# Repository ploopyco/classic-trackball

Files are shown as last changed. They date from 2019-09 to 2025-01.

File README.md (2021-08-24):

# The Ploopy Trackball

By some stroke of luck, you've made your way here. The Ploopy Trackball. Your life will never be the same.

This repository contains all of the design and production files necessary to make a Ploopy Trackball. We've also included some kick-ass documentation in the Wiki on how to get it made, assemble it, and program it.

What are you waiting for? Your new life awaits.

## QMK?!

As of November 13th, 2020, kits bought from the [Ploopy store](https://ploopy.co/product-category/trackball/classic/) come with QMK preloaded. Check out the Wiki for instructions on how to load new firmware onto your device. (It's super easy!)

## Under what license is this released?

The firmware is released under GPLv3. The hardware is released under OHL CERN v1.2. Check the respective directories for full license text.

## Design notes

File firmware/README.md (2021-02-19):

# Deprecation Notice

As of November 13th, 2020, this firmware is considered DEPRECATED and should no longer be used.

If you purchased an official Ploopy Kit and received a notice of shipment prior to November 13th, your kit includes this firmware. If your kit shipped after this date, it comes with [QMK](https://github.com/qmk/qmk_firmware).

This firmware will still work with PCBs of version R1.005, and the firmware in [R1.004 branch](https://github.com/ploopyco/trackball/tree/r1.004) will still work with PCBs of version R1.004 and previous. But you really ought to switch to QMK. It's the shit.

Sample builds of QMK are included here, for board versions prior to R1.005 (the `rev1` hex) as well as the R1.005 board and later (the `rev1_005` hex). They were built using QMK version 0.11.1.

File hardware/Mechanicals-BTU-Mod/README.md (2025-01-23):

# Ploopy BTU Mod

The roller bearings used in the Ploopy Trackball are nice, but with the standard ball they might not feel as smooth or as low-friction as you'd like. The prompt for this mod was "what if we replaced them with ball transfer units?"

It turns out - good things happen!

Ball transfer units (or BTUs) are omnidirectional bearings, as opposed to the single-direction roller bearings the Ploopy Trackball uses by default. This means you're never rolling the ball in the "wrong direction" for one of them.

This mod is a new 3D-printable top piece for the Ploopy which contains holes for ball transfer units instead of roller bearings.

Designer: [George Bryant](https://github.com/gbrnt) with help and bearing advice from [/u/d4baller](https://reddit.com/user/d4baller)
## Versions
### REVD-BTU
This version is the version you should use if you have a REV D Ploopy top.
You can check this on the underside of your original top - there should be a large letter D,
and your screws will be self-tapping screws.
It supports both the original ball and the new larger (45mm) ball.

### REVC-BTU
This version is the version you should use if you have a REV C Ploopy top.
You can check this on the underside of your original top - there should be a large letter C,
and your screws will be M3 screws.
It supports both the original ball and the new larger (45mm) ball.

### v3 and v4
These versions are too small to fit the new larger ball.
They've been removed, but you can still find them in the commit history.
v3 is a non-editable version that exposes the edge of one BTU, and v4 is an editable FreeCAD version.
Here's what they look like:

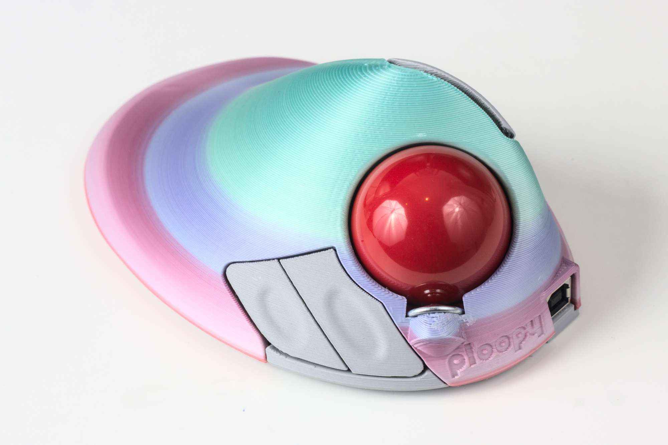
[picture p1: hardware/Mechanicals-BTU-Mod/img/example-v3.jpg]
A trackball with this mod v3 installed


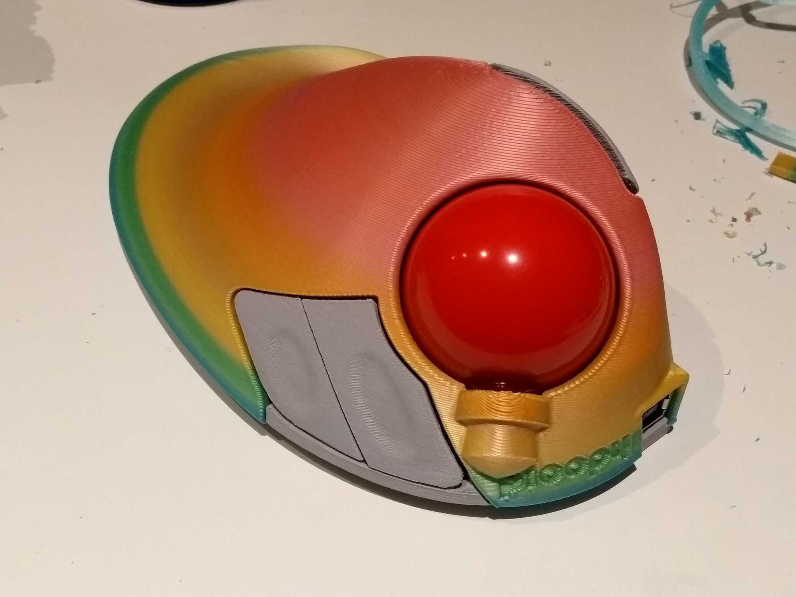
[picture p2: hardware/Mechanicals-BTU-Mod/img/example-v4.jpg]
A trackball with the v4 mod installed


## Buying the BTUs
The particular BTU this mod is designed for is the Bosch-Rexroth R053010810, or KU-B8-OFK. A set of three is about 20-30 USD, depending on where in the world you are and where you buy them from. Here are some sources we've found so far:

* [Bosch-Rexroth](https://www.boschrexroth.com/en/xc/products/product-groups/linear-motion-technology/ball-transfer-units-and-tolerance-rings/ball-transfer-units/r0530-with-sheet-stee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) - UK and worldwide, but requires you to be a company (e.g. have a VAT number)
* [Livhaven](https://store.livhaven.com/r053010810-bosch-rexroth-ball-transfer-unit) - US-based. Doesn't require company information, but overseas shipping is expensive.
* [Uberbearings](https://www.uberbearings.com/R053010810KU-B8-OFK-BOS) - Ships from UK worldwide to private customers. Much cheaper shipping than the other Europe based ones.
* [L-System](https://l-system.nu/webshop/linear-technology/ball-transfer-units-and-tolerance-rings/ball-transfer-units/type-r0530/ball-transfer-unit-ku-b8-ofk/) - Sweden-based. Might allow private customers to buy.
* [Spareparts](https://www.sp-spareparts.com/en/p/r053010810-bosch-rexroth) - Ireland-based. Ships to UK and maybe elsewhere. Does sell to private customers.
* [Rodivago](https://rodavigo.net/es/p/bola-transportadora-con-carter-de-metal-laminado-ref-053010810/557053010810) - Spain-based. May require being a company.
* For other sources, try Bosch-Rexroth's [contact locator tool](https://addresses.boschrexroth.com/) - find a distributor near you, and search for the bearing part number on their website.

(Some people consider buying cheaper nylon BTUs. But they have high internal friction and the ball actually slides on them like on a static bearing, which makes them pointless.)

## Printing
Follow [Ploopyco's recommendations for print settings](https://github.com/ploopyco/trackball/wiki/Appendix-B%3A-3D-printed-parts). It's also highly recommended to enable support interface and splitting the support into chunks, as otherwise it can be very hard to remove.

## Assembly
* Remove all support material from the print.
* Inspect the holes the BTUs will sit in to make sure there are no lumps inside the hole. File/sand/cut them off if needed.
* Install the BTUs by pushing them into the holes.
* Check the BTUs are fully installed by putting the ball on top. It shouldn't scrape on the top surface. If it did one or more of the BTUs might not be fully pushed in.
* Check that the holes for the threaded inserts are clear (You could carefully drill them out with a 4mm drill bit).
* Install 4 M3 threaded inserts into the bottom of the part using a soldering iron (see note below).
* Remove the original top piece from your Ploopy trackball.
* Remove the secondary button piece, grind off the stop (see below) and reinstall.
* Install the new top piece on the trackball.
* Give it a try!

### Threaded inserts (Ignore if using REV D)
You'll need 4 heat-set M3 threaded inserts for the screws which attach the top to the base.
These can be bought from a variety of sources - you should use ones which are made for 4.0 - 4.2mm holes.
Recommendations for installing these are in the [Ploopy trackball assembly guide](https://github.com/ploopyco/trackball/wiki/Ploopy-Trackball-Kit-Assembly).

### Modifying secondary buttons
There is a small tab on the secondary buttons which collides with the closest BTU. It needs to be sanded, filed or cut off. It is indicated in red in the image below:

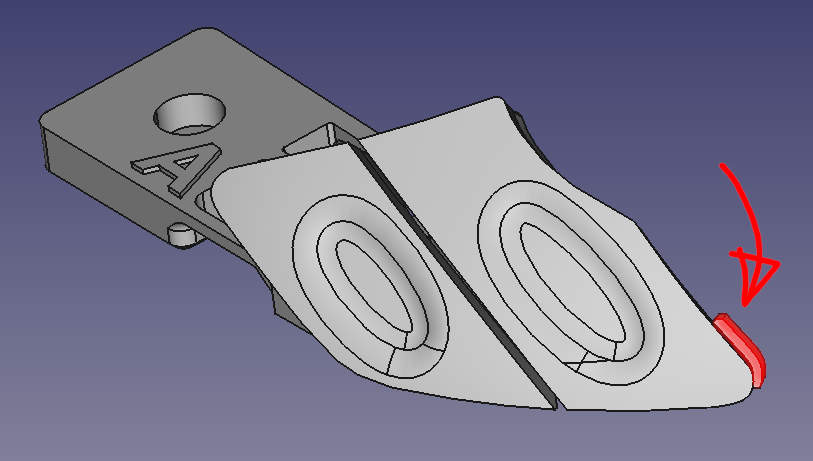
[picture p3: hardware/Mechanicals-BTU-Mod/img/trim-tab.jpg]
Ploopy secondary buttons, with the tab on the end highlighted in red


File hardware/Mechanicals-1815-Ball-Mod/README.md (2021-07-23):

This Top accommodates balls that are 1.815" in diameter, a ball that can be found in such devices as the Microsoft Trackball Explorer.

Credit goes to an anonymous redditor. Thanks for the contribution!

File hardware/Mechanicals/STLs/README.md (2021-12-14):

The files in each "Revision" directory are designed to work with each other. For instance, all of the files in Revision A are designed to work as a unit.

**NOTE** that even though a Revision is marked with a letter, not all of the parts have this letter. For instance, in Revision D, the buttons are actually marked with a C. This is intentional.

Files in this directory are common to all revisions.

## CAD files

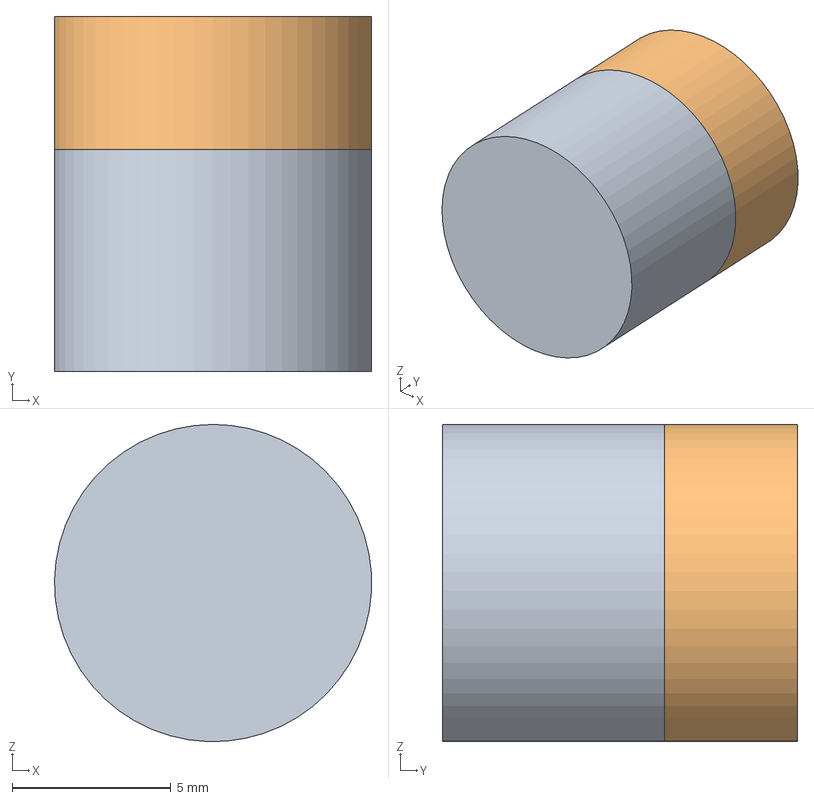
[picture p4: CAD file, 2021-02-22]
hardware/Mechanicals/STEPs/Bit Bearing Press Complete.step
9.99 x 11.2 x 10.00 mm

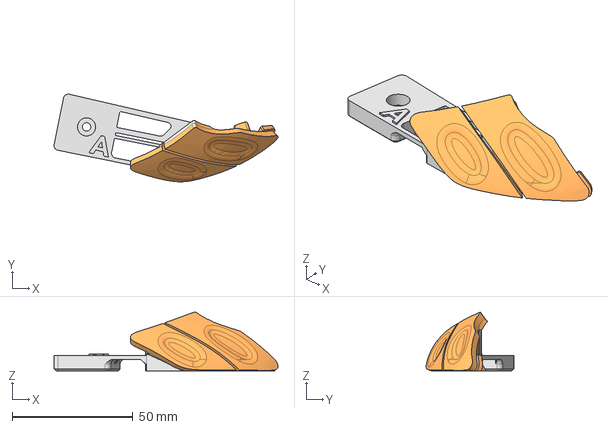
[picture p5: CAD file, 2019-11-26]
hardware/Mechanicals/STEPs/Revision C/Secondary Buttons.stp
92.8 x 36.3 x 24.3 mm

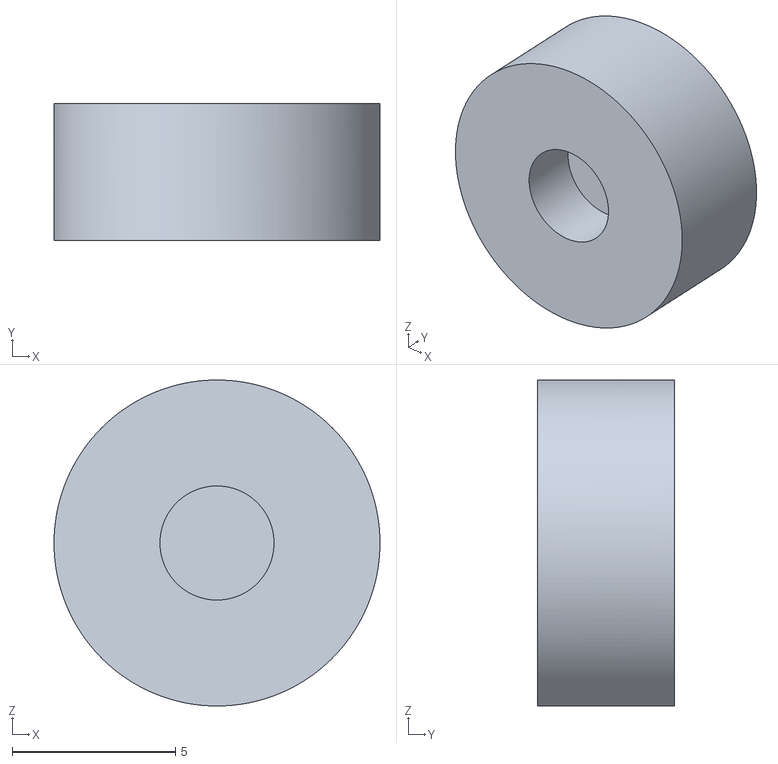
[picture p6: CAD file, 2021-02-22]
hardware/Mechanicals/STLs/Kit Bearing Press Top.stl
10.00 x 4.20 x 10.00

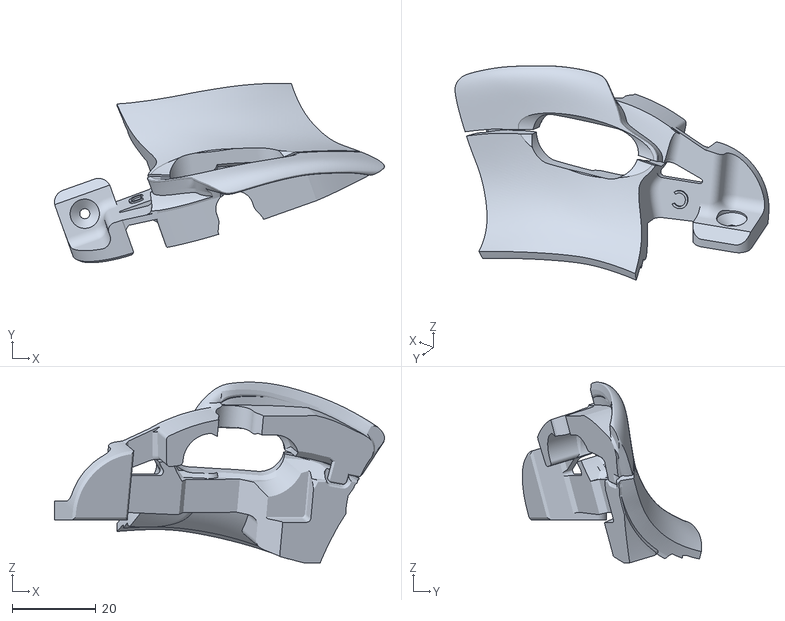
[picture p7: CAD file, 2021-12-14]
hardware/Mechanicals/STLs/Revision D/Primary Buttons.STL
78.9 x 42.9 x 43.2

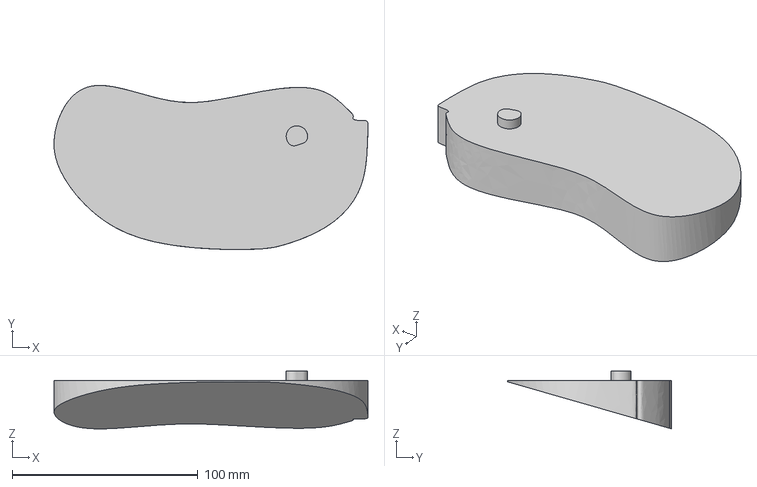
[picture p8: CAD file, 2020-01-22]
hardware/Mechanicals/STEPs/Wedge.stp
169.1 x 88.4 x 31.0 mm

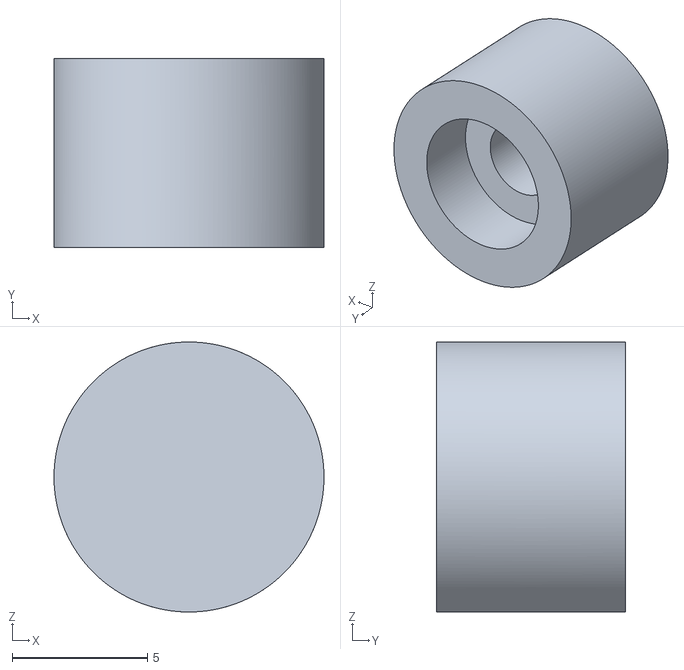
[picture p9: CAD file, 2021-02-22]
hardware/Mechanicals/STLs/Kit Bearing Press Bottom.stl
10.00 x 7.00 x 10.00

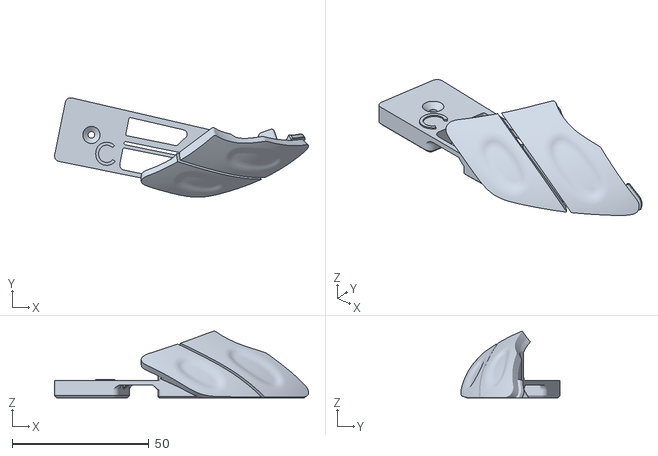
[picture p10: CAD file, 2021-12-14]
hardware/Mechanicals/STLs/Revision D/Secondary Buttons.STL
92.8 x 36.3 x 24.3

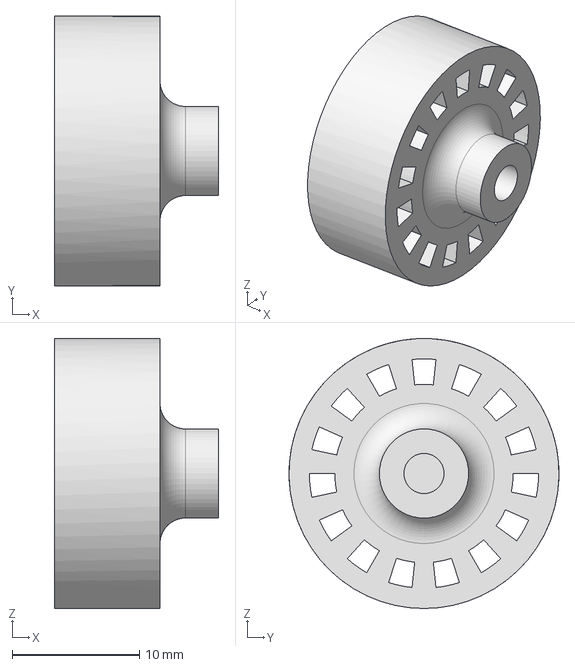
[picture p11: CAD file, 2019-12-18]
hardware/Mechanicals/STEPs/ScrollWheel.stp
12.9 x 21.2 x 21.2 mm

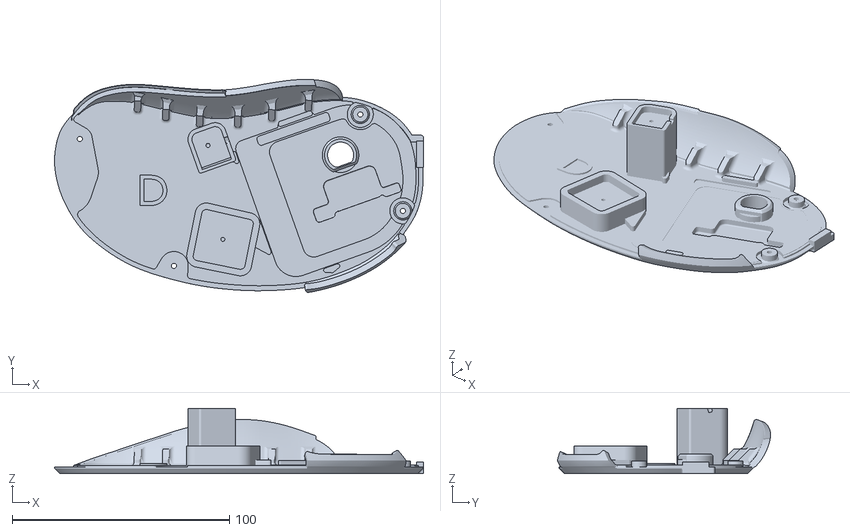
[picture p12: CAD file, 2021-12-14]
hardware/Mechanicals/STLs/Revision D/Bottom.STL
170.0 x 98.3 x 30.0

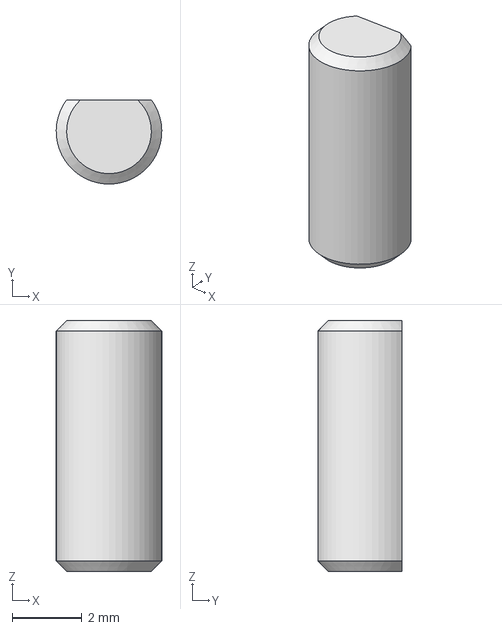
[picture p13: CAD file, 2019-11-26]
hardware/Mechanicals/STEPs/RollerBearingDowel.stp
3.03 x 2.42 x 7.20 mm

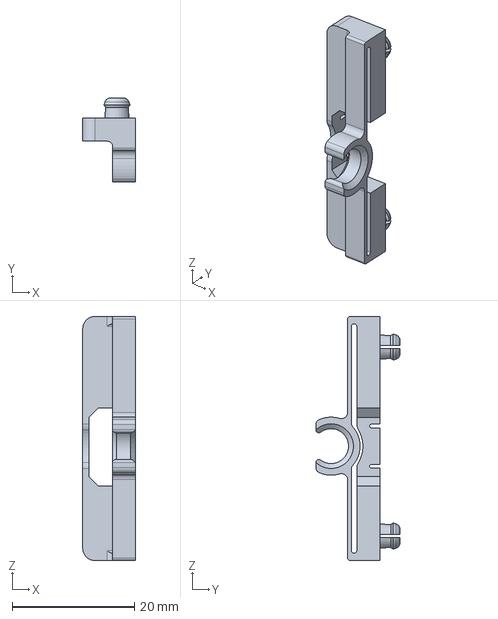
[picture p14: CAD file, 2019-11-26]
hardware/Mechanicals/STEPs/ScrollWheelHolderHolder.stp
8.60 x 13.8 x 39.9 mm

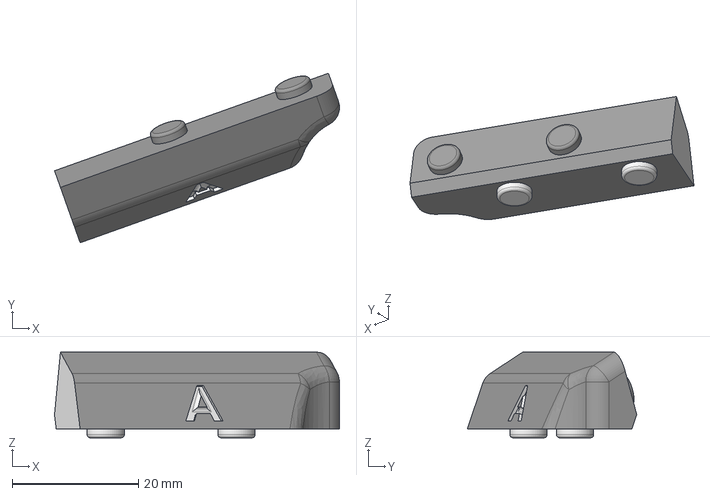
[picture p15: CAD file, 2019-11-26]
hardware/Mechanicals/STEPs/PCB Anchor.stp
45.1 x 26.9 x 13.6 mm

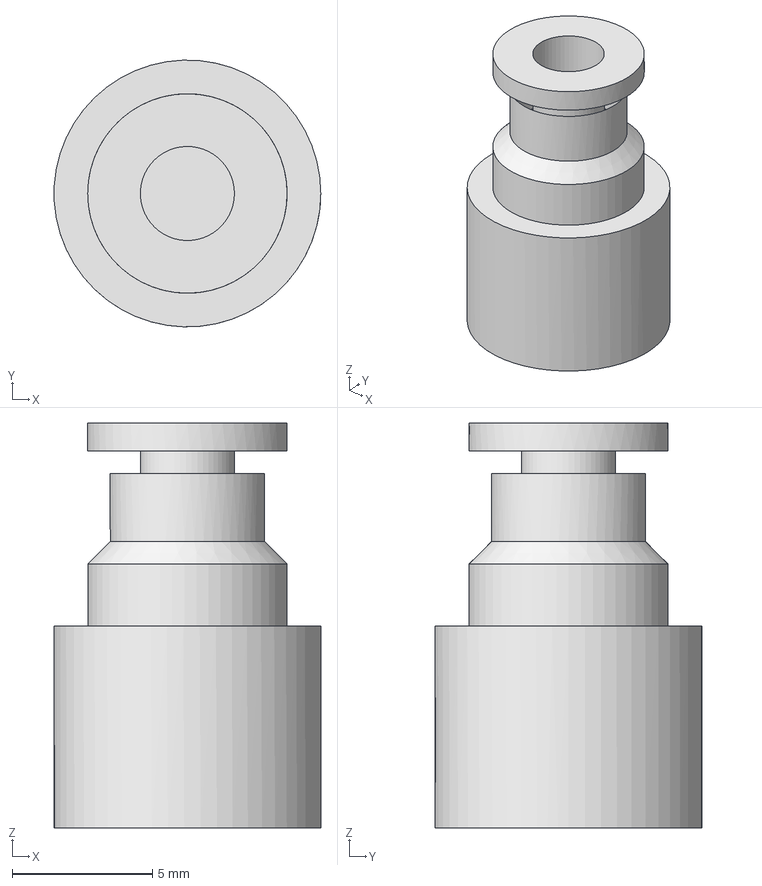
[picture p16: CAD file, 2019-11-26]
hardware/Mechanicals/STEPs/ScrollWheelHolder.stp
9.49 x 9.50 x 14.4 mm

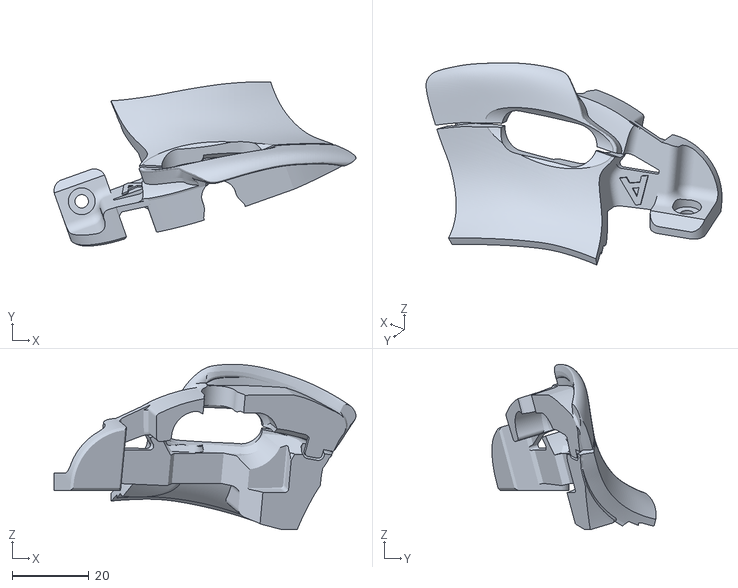
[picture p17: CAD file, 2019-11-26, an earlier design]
hardware/Mechanicals/STLs/Revision A/Primary Buttons.stl
78.9 x 42.9 x 43.2

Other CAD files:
hardware/Mechanicals/STLs/Revision C/Primary Buttons.stl
hardware/Mechanicals/STLs/Revision C/Bottom.STL
hardware/Mechanicals/STLs/PCB Anchor.stl
hardware/Mechanicals/STLs/Revision A/Secondary Buttons.stl
hardware/Mechanicals/STLs/Revision C/Secondary Buttons.stl
hardware/Mechanicals/STLs/RollerBearingDowel.stl
hardware/Mechanicals/STLs/ScrollWheel.stl
hardware/Mechanicals/STLs/ScrollWheelHolder.stl
hardware/Mechanicals/STLs/ScrollWheelHolderHolder.stl
hardware/Mechanicals/STLs/Wedge.stl

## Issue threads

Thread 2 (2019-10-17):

Handedness

hlieberman, 2019-10-17:
Hello!

I don't know if you've thought about handedness at all during this design, but how difficult of a process would it be to try and mirror the mouse over to create a left-handed version?

I imagine the PCB would also have to be mirrored, because the vertical section needs to be on the correct side, but would it just be a matter of flipping everything - stl's, and the pcb itself - along the y axis? Or is that going to spiral out of control into new and exciting problems?

Closed 2019-11-25.

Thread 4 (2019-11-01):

PS/2 Output

equalunique, 2019-11-01:
An outdated protocol is an odd thing to ask for, but I thought I'd try anyway. Is PS/2 output something that you've considered? Do you have any thoughts on level of effort? I'm imagining it would not be compatible with the current PCB.

I'm interested in connecting a Ploopy Mouse to a keyboard running QMK firmware, as described [here](https://beta.docs.qmk.fm/features/feature_ps2_mouse) and shown [here](https://github.com/qmk/qmk_firmware/issues/5218#issuecomment-475496870).

Being able to connect it to QMK would allow me to bundle mouse and keyboard functionality into a single device, which paves the way to an integrated design, bluetooth, and more. :)

I'm really not an expert, but a little overview shows Ploopy firmware using C++, which is also what the [ps2dev](https://github.com/Harvie/ps2dev) Arduino library uses.

ploopyco, 2019-11-01:
Yeah, swapping the USB connector for PS/2 would be a new PCB, new hole in the enclosure, and new firmware. It'd basically be a new project.

[One of the QMK devs has been working on porting it over to this mouse](https://www.reddit.com/r/Trackballs/comments/dk4ha7/ploopy_vs_elecom_huge_now_with_qmk/). Just saying.

ChasonDeshotel, 2019-11-13:
That post is actually how I found Ploopy, love QMK, Ploopy Trackball looks amazing. Bluetooth would be sick

ploopyco, 2020-04-27:
Closing for lack of follow-up interest.

mmuman, 2020-10-15:
Well, first generation USB mice had support for PS/2 using a passive adapter that just turned the USB plug into a mini-DIN.

It should just be a matter of detecting levels on the data signals and bit-bang PS/2. But sadly the chosen uC puts USB signals on single-function pins, so you can't reprogram them to be GPIOs. It may be possible to work around this if the USB core can be put to standby (and have D+/- as high-impedance, and if the current design has 2 free GPIOs. In this case, adding 2 wires should be the only mod required. The firmware would start by turning USB down, setting the GPIOs to detect the levels, set them up for PS/2 if detected, or turn them off and USB back on in the other case.

Closed 2020-04-27.

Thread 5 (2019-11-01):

Second Sensor and Twist Scrolling

kamegami13, 2019-11-01:
I'm curious if it's possible to add a second sensor so it can do twist scrolling like the Kensington Slimblade. On a similar note, if it was possible to use for 1:1 rotation control for CAD/modeling programs. My understanding is that with two sensors you could track all three axis' of rotation.

ploopyco, 2019-11-01:
At the minimum, my gut feeling is that it would require a third PCB (to house the sensor, which needs to be positioned from the ball at a very precise distance). Changes to the enclosure, too, to hold the new PCB, as well as a new hole.

I'm not thrilled about the idea. I wanted a very specific set of features in this design, and I'm happy with where it's ended.

ChasonDeshotel, 2019-11-13:
Sounds awesome. With [QMK running on this unit now](https://www.reddit.com/r/Trackballs/comments/dk4ha7/ploopy_vs_elecom_huge_now_with_qmk/f4akfnh/) writing custom code is possible, so I imagine the difficulties will be finding an extra input on the PCB (or making a new one) and modifying the enclosure

>the sensor [...] needs to be positioned from the ball at a very precise distance

Is this a physical limitation of the sensor itself or could it be overcome via a configuration variable on QMK?

>I'm happy with where it's ended

As you should be, this project is seriously badass

>My understanding is that with two sensors you could track all three axis' of rotation.

That sounds about right

Closed 2020-04-27.

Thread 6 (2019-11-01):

Thumb trackball

pianohacker, 2019-11-01:
If I were motivated to customize both the enclosure and the PCB, how hard would it be to make a thumb trackball version of this? (Something like the MX Ergo.) I’m thinking that the electronics and firmware might be reusable, with some modifications to the PCB and plastic. Thoughts?

ploopyco, 2019-11-05:
Hm. Interesting. Not sure I can declare how difficult that would be. If there are four buttons and a trackball with a single sensor, then the firmware should be completely reusable.

The electronics could be pretty similar, too. I imagine that the PMW3360 sensor would sit on the vertical board instead of the base board, since the sensor would probably have to sit at an angle.

The enclosure would be completely different. I don't think it'd be worth it to reuse my enclosure. Probably best to just start from scratch.

Closed 2020-04-27.

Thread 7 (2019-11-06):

[suggestion] Middle/ringfinger trackball

krono, 2019-11-06:
simliar to #6, if there should be variants, one like the Logitech Cordless Trackman Optical T-RB22 would be cool. since the trackball is only shifted a bit to the right, this shouldn't be as complicated

ploopyco, 2019-11-11:
I don't have any plans to make case variants.

I certainly have an opinion on the complexities of altering the enclosure, but if some enterprising individual was to come along and think to undertake the task, I wouldn't want to discourage them.

Closed 2020-04-27.

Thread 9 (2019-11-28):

Missing dowel in Appendix D: Hardware

Lilolbet, 2019-11-28:
First off, this looks like a pretty neat project. Very interested in building a mouse and upgrading from my Logitech M570. I however don't see the what dowel is required for the bearings (Step 17 in 3. Enclosure assembly).

Will look though all remaining files (if I find it, ill reply with the answer). Regardless, this information is still missing on both the Hardware and Assembly pages.

ploopyco, 2019-11-29:
The roller bearing dowel can be found [here](https://github.com/ploopyco/mouse/blob/master/hardware/Mechanicals/STLs/RollerBearingDowel.stl) as a STL, and [here](https://github.com/ploopyco/mouse/blob/master/hardware/Mechanicals/STEPs/RollerBearingDowel.stp) as a STEP.

Lilolbet, 2019-11-29:
Well this is embarrassing. Looking at the picture I was sure it was a metal part.

Thank you for clarifying.

Closed 2019-11-29.

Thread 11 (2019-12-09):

Bluetooth?

mseflek, 2019-12-09:
Hi,

Fantastic project. Any plans to make a bluetooth version or add on?

King-Icewind, 2019-12-09:
I (contributor) am currently working on rebuilding this in KiCad. Along with adding USB C and a few other minor changes, I intend to add battery charging and Bluetooth support (in a future version). I haven’t decided on if it will be an add on to the main board or a new board altogether.

ploopyco, 2019-12-10:
Nice @King-Icewind. I'm excited to see these changes. Out of curiosity, what sort of batteries are you planning on using? NIMH? Li-ion? Any plans for the housing, or will the batteries just be taped to the enclosure?

King-Icewind, 2019-12-10:
I've only ever worked with Li-ion in my projects, so I'll likely go that route. I can have 3.3v+ in a smaller package. I haven't drawn anything yet, however, I think a 3D printed battery holder that shares the rear two screw mounts of the base might work.

diabl0w, 2020-03-14:
pinging @King-Icewind any updates on this? I also saw your reddit thread

King-Icewind, 2020-03-14:
The board is all designed; I just have to order some made to test.

I put the project on a temporary hold with the whole COVID19 thing. 5 boards from China was around $100, otherwise it was $300+. Looks like I could probably order them now though.

diabl0w, 2020-03-14:
> @diabl0w The board is all designed; I just have to order some made to test.
>
> I put the project on a temporary hold with the whole COVID19 thing. 5 boards from China was around $100, otherwise it was $300+. Looks like I could probably order them now though.

yes its certainly a strange time, I hope everyone stays safe.

I look forward to checking out the new boards, I hope they end up working out. nothing better than having your design work first try 😅 thanks for advancing this project and ploopyco for the original project

Closed 2020-04-27.

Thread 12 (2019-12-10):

Scrolling has finiky bug

nerd7473, 2019-12-10:
Scrolling makes content move up and down rapidly at certain points while scrolling. How would we implement a patch? Is there a patch yet?

nerd7473, 2019-12-10:
Bug seems to be fixed when you unplug the mouse, and plug it back in...

King-Icewind, 2019-12-10:
Did you hand solder your board?

nerd7473, 2019-12-10:
No, I didn't this was the hand assembled one from ploopyco

nerd7473, 2019-12-10:
Works like a dream after you unplug and plug it... But not sure why the bug exists in the first place.

King-Icewind, 2019-12-10:
I asked because it may be an issue with the IR emitter and/or phototransistors, or scroll wheel. There are spaces/holes in the scroll wheel: when the spaces break the IR beam it will tell the MCU there's scrolling happening. You can check your scroll wheel to make sure there is nothing in the tiny holes along with checking the vertical board for anything in the way of the IR emitter and transistors. If one of the IR emitters is slightly angled, it may cause an issue too.

This is a bit of a guess at what is wrong, but hopefully you are able to figure it out.

nerd7473, 2019-12-10:
As I said, after unplugging and plugging it in... I works fine, I do have another trackball on the system and that's a Logitech M570... Zorin 15 (Basically GNOME Shell rebranded) I have also had the issue on my Ubuntu laptop (running Unity 7.4). But after unplugging and plugging the bug goes away as long as I don't lock or reboot the system... Otherwise no issues... So it may be that GNOME-based shells have an issue with working with this mouse...

ploopyco, 2019-12-18:
I've been working on addressing this, and I think that I've found the root cause: the scroll wheel itself isn't correct. I've since updated the STEP and STL file for the wheel to have a different number of holes.

Send me an email at contact [at] ploopy {dot} co and I'll get a replacement to you, if you don't have access to a 3D printer. Once you've tested it, we can revisit this issue.

Closed 2020-04-27.

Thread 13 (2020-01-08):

sourcing pmw 3360

bobwmcgrath, 2020-01-08:
I am having a hard time sourcing this sensor.  would you mind sharing where you are getting them from?  please and thankyou.

King-Icewind, 2020-01-08:
You can order it here: https://www.aliexpress.com/item/32855955475.html?spm=a2g0o.cart.0.0.5daf3c00KOZuk7&mp=1

bobwmcgrath, 2020-01-08:
nice, that one even comes with the lens.  thanks

Closed 2020-04-27.

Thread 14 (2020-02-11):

Use ATmega32u4-AU to get factory DFU bootloader

Duckle29, 2020-02-11:
Hi there. I noticed the docs talk about putting new firmware on the board using an Arduino nano as an ISP programmer.
While that certainly would work, it's maybe a bit involved when there's already lots of cheap ISP programmer options available, like the USBtinyISP, the USBasp, and more.

That said, it shouldn't even be necessary, as all ATmega32u4 chips that come configured to use an external crystal (non RC versions), also ship with Atmel-DFU pre-programmed, and as such can be programmed over USB.

The datasheet has a mistake in Table 33.2, but I've gotten clarification that the statement on the first page of the datasheet

> Parts using external XTAL clock are pre-programed with a default USB bootloader

is indeed correct:

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

Figured I'd let you know for future batches :)

ploopyco, 2020-04-27:
Thank you for looking into this.

Boards that we make already use the -AU variant (though they're shipped with mouse firmware already on-board). The instructions are written with the understanding that not everyone has access to these pre-programmed parts. This way, everyone making their own can program theirs, no matter what kind of chip they managed to get their hands on.

Closed 2020-04-27.

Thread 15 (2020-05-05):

Missing stl of electronics assembly jig

Lilolbet, 2020-05-05:
I apologize in advance, since I assume I am at fault here.

For the life of me I can not find the .stl file for the electronics assembly jig. Is this available? I have checked out various commits and I can not find it anywhere.

The jig is the following one:

![Image](https://camo.githubusercontent.com/66248733af3e0b12f129085036c497171f856f5d/68747470733a2f2f6c68332e676f6f676c6575736572636f6e74656e742e636f6d2f754167785a72564a65772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)

ploopyco, 2020-05-05:
You're correct - it's not in the repository. They're only included in kits bought from the store.

Strictly speaking, that jig isn't necessary to complete assembly (as can be seen [here](https://github.com/ploopyco/mouse/wiki/2.-Electronics-assembly)).

Lilolbet, 2020-05-05:
Ahhh! Thank you, I thought I was going crazy :)

Closed 2020-05-05.

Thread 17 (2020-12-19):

Scroll Wheel detent

Grifplex, 2020-12-19:
I've been loving the trackball kit for almost a year. My hand fatigue has improved since ditching the normal mouse. There is just one thing about it that bugs me, the scroll wheel can get in a spot such that clicking moves it just so that it scrolls. This can be fixed with a detent to help the scroll wheel stay away from the transition points when at rest. I'm just not sure how to implement it. Something like a spring loaded nub that runs into the hole from the scroll wheel holder holder.
Thanks, Nick.

Grifplex, 2021-01-04:
It has been behaving much better since I printed a new thumbwheel. The larger hole design still could use a detent.
Thanks, Nick.

Grifplex, 2021-03-10:
Still getting a scroll when I click sometimes. Any suggestions?

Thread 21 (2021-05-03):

Using the trackball as a scroll wheel

lacymorrow, 2021-05-03:
As a user of the Ploopy classic and nano trackballs, I would like the ability to hold down a key combination (both forward/back buttons together, for example) which would allow the trackball to act as a 2D scroll wheel, rather than a mouse input.

There are OS-specific solutions like Logitech Marblemouse software or AutoHotKey scripts that can accomplish this, but QMK also has the ability and would remove the OS restrictions and complicated setups.

I probably don't know enough or have enough experience with QMK to help, but I'd imagine this is a pretty common wish for trackball users.

GDsouza, 2021-05-18:
@lacymorrow As far as I am aware, the firmware is a part of the QMK repo. There is a [drag_scroll keymap](https://github.com/qmk/qmk_firmware/tree/master/keyboards/ploopyco/trackball/keymaps/drag_scroll) upstream, which is what I'm currently using to make the trackball act as a 2D scroll wheel.

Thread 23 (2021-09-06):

ScrollWheel.stp has 15 holes, not 13

HomerSp, 2021-09-06:
Don't know if I'm doing something wrong, but when I open ScrollWheel.stp in FreeCad I see it has 15 holes, not 13 like the STL.
I probably wouldn't even have noticed this if it wasn't for the fact that when I had printed the step file, the scroll direction would be reversed. Not sure what causes this, but I'm guessing it has something to do with the holes being slightly smaller?

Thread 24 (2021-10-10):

Trackball/Mouse movement unresponsive after few seconds

diabl0w, 2021-10-10:
OS: Linux
Firmware: latest QMK

Issue: After using the trackball then stopping, after a few seconds trackball/mouse movement becomes completely unresponsive. If i click a button on the mouse then the trackball becomes usable again, and then the problem repeats after stopping the use of the trackball.

Already tried: disabling usb powersave via udev rule

Closed 2021-10-10.

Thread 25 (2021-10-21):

PCB layer sequence?

JonnyHaystack, 2021-10-21:
Hi, I'm not sure how to put in the layer stackup/sequence to get the main PCB manufactured from JLCPCB.

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

Could you advise on this, and maybe put something in the wiki [Appendix A](https://github.com/ploopyco/classic-trackball/wiki/Appendix-A%3A-Printed-circuit-boards) about it?

Thanks

cyberhuman, 2023-03-22:
Hey! Have you find the solution?

gbrnt, 2023-03-22:
The files we have are:
* Base.apr
* Base.EXTREP
* Base.G1
* Base.G2
* Base.GBL
* Base.GBO
* Base.GBS
* Base.GD1
* Base.GM2
* Base.GTL
* Bse.GTO
* Base.GTP
* Base.GTS
* Base-macro.APR_LIB

Looking at [this site](https://www.vse.com/blog/2022/03/08/gerber-file-names/) it says:
- APR: Aperture file
- GTL: Board top layer
- GTB: Board bottom layer
- G1, G2, etc.: Inner layers
- GP1, GP2, etc.: Power and ground plane layers

So JLCPCB's layer names:
- L1 (Top Layer) -> Base.GTL
- L2 (Inner layer 1) -> Base.G1
- L3 (Inner layer 3) -> Base.G2
- L4 (Bottom layer) -> Base.GTB

I'm not familiar with Gerber files so not sure what the rest are.

ploopyco, 2024-04-08:
Closing; we can't advise on your relationship with your board house.

Closed 2024-04-08.

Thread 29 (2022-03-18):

REVD-BTU mod doesn't fit ball

Auncaughbove17, 2022-03-18:
Hi! I let someone print me the [REVD version](https://github.com/ploopyco/classic-trackball/blob/master/hardware/Mechanicals-BTU-Mod/STL/Ploopy-Top-REVD-BTU.stl) of the BTU mod,
but the ball doesn't fit. With or without the BTUs in place. The hole seems too small..
Here are some pictures comparing the original top part with the new BTU part. Am I doing something wrong? Should I sand down the new part?
I believe @gbrnt designed this, I couldn't make an issue on his fork however.

<details>
  <summary>Click to view the images!</summary>

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
</details>

UPDATE:
I sanded the inner part down, and also bought a 44.5mm billiard ball. Though there are still issues and I think the model is of the wrong size! Here are some images and videos regarding the mouse, which shows the way it's too small. https://photos.app.goo.gl/rMXwHFF1sCEd3Zp79

The person who printed the model for me gave me some additional insight as well! First of all, it seems unlikely that the issue was in the print. The person in question has according to his own statements, 8 years experience with 3d printers and a professional 3d printer that allows for 1x1x1m prints, also

    the tolerance is 0.01 mm from the printer which is very accurate. so the model can only deviate from the drawing by 0.01 and that is not noticeable in the print. I think something about the drawing is wrong. but what struck me is that both drawings I received were exactly the same size.

He also sent me an image comparing the model to the original revd top stl model from github and there is indeed a difference in length of the model visible.
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

My conclusion at this point is thus, that the BTU model has to be increased in size. Though I would like some other professional have a look at it. Especially [/u/FredCompany](https://old.reddit.com/u/FredCompany) / @gbrnt
since he seems to have created the model.

gbrnt, 2022-03-25:
As mentioned in the reddit comments about this, this is because I missed something when making the REVC/REVD changes to the BTU mod. In your screenshot you can see that the REVD top has a much wider hole, while on the BTU top the curve extends further over the ball. I should be able to fix this.

Also, in your screenshot I don't think that's the REVD BTU top - it doesn't have the extra piece that hides the BTU. That was an earlier version. It's not the cause of your issue as the one you've printed isn't the same one that's in the screenshot.

gbrnt, 2022-03-25:
It looks like I lost track of versions at some point (because my original Rhino files aren't tracked in Git since they're large) and applied the REVD changes to the REVA BTU top instead of the REVD BTU top. There's a bit of a mess for me to sort out here.

gbrnt, 2022-03-28:
This should be fixed in [this commit in my fork of the repo](https://github.com/gbrnt/ploopy-classic/commit/25cbf3994e283b2e497a7e64d7ee26e42d14b42b). Please give it a try and report back, then I can ask ploopyco to merge it!

Auncaughbove17, 2022-03-28:
Ok, Thanks! I will let this file be printed now. I will let you know how it turned out.

Auncaughbove17, 2022-04-04:
> This should be fixed in [this commit in my fork of the repo](https://github.com/gbrnt/ploopy-classic/commit/25cbf3994e283b2e497a7e64d7ee26e42d14b42b). Please give it a try and report back, then I can ask ploopyco to merge it!

Now it fits! So, your changes worked!

Closed 2022-04-04.

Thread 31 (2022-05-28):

Bootloader button mismatch

TheMitchelson, 2022-05-28:
The section of Appendix C: QMK Firmware Programming describing which buttons need to be pressed to enter the booloader appear to be backwards at the top.
https://github.com/ploopyco/classic-trackball/wiki/Appendix-C%3A-QMK-Firmware-Programming

>     If you've got a right-handed Ploopy Classic, hold the **"forward" button** and plug in the trackball. If moving the ball doesn't move the cursor, then you've got QMK. (Try unplugging and plugging it back in without holding the forward button just to make sure that moving the ball still works as normal.)

But then later when it discusses it:
> If you're using a right-handed Ploopy Classic, hold the **"back" button**. This is the button just to the right of the ball; it normally sits under your ring (fourth) finger. If you're using a left-handed Ploopy Classic, hold the "forward" button.
This later one appears to be the correct one as it's what worked for me.

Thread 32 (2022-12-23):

Purchase electronics only?

JamesNewton, 2022-12-23:
Is there no option to purchase /just/ the electronics? I have printers, I have general hardware, I'd really like to just buy the PCB and maybe the ball? No?

gbrnt, 2022-12-24:
I've seen this asked a few times on Reddit and the answer has been that the printed parts are so cheap in comparison to the rest there's not really any reason *not* to send them.

cyberhuman, 2023-03-22:
They may be cheap but some people want to be sustainable and not generate more garbage than really needed :-(

imme-emosol, 2023-08-25:
Would you buy the option if it was priced the same?

Somewhat related is that I would be interested in offering the extra parts from all recycled plastics.

imme-emosol, 2023-08-26:
Issue can probably be closed
~ https://blog.ploopy.co/why-we-dont-offer-kits-without-3d-printed-parts-52 .

Closed 2024-04-08.

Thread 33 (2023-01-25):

STL/STEP file - revision mismatch

Bobblybook, 2023-01-25:
Hi,
I've recently tried printing a rev C base and top (BTU modded).
I've just noticed after printing that the "rev C" version actually has "A" embossed on the base.
I've double checked what I printed:

The Rev. C STEP file has "A" on the base
The Rev C STL appears to have the correct "C"

It seems like only the STEP has the incorrect design - I'm not sure if it's only the lettering, or the whole model is old and not really rev C.
I also haven't checked any of the other versioning, I have only run into this one so far. Are the STEP files more accurate? I don't want to realise I need to reprint a lot of material.
Thanks

gbrnt, 2023-01-25:
If I remember right only revision D of the trackball changed the base. Until then rev A of the base was used. So Rev A base should work for rev A-C tops (unless I've forgotten how it works).

Not sure what the deal is with the tops, and I don't have the free time at the moment to properly investigate, unfortunately.

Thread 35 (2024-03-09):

Broken link at Appendix A: Printed circuit boards

rosso-, 2024-03-09:
The link [the source](https://github.com/ploopyco/mouse/tree/master/hardware/Electronics/Gerbers) at [Appendix A: Printed circuit boards](https://github.com/ploopyco/classic-trackball/wiki/Appendix-A%3A-Printed-circuit-boards) is broken.

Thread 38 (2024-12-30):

Appendix C: No rule to make target 'via'

rlperez, 2024-12-30:
Using the master branch qmk firmware it appears that there is no via keymap found when trying to follow the instructions in the wiki page. Perhaps this step is not required anymore? The only keymap I see is default. It would seem as though perhaps this step isn't required anymore?

```
❯ git branch -vv
* master f549948b [origin/master] Skip parsing g_led_config when matrix_size is missing (#24739)

❯ qmk --version
1.1.6

❯ make ploopyco/trackball/rev1_005:via
QMK Firmware 0.27.3
Making ploopyco/trackball/rev1_005 with keymap default and target via

make[1]: *** No rule to make target 'via'.  Stop.
Make finished with errors
make: *** [Makefile:415: ploopyco/trackball/rev1_005:via] Error 1

❯ qmk compile -kb ploopyco/trackball/rev1_005 -km via
☒ Invalid keymap argument.
```

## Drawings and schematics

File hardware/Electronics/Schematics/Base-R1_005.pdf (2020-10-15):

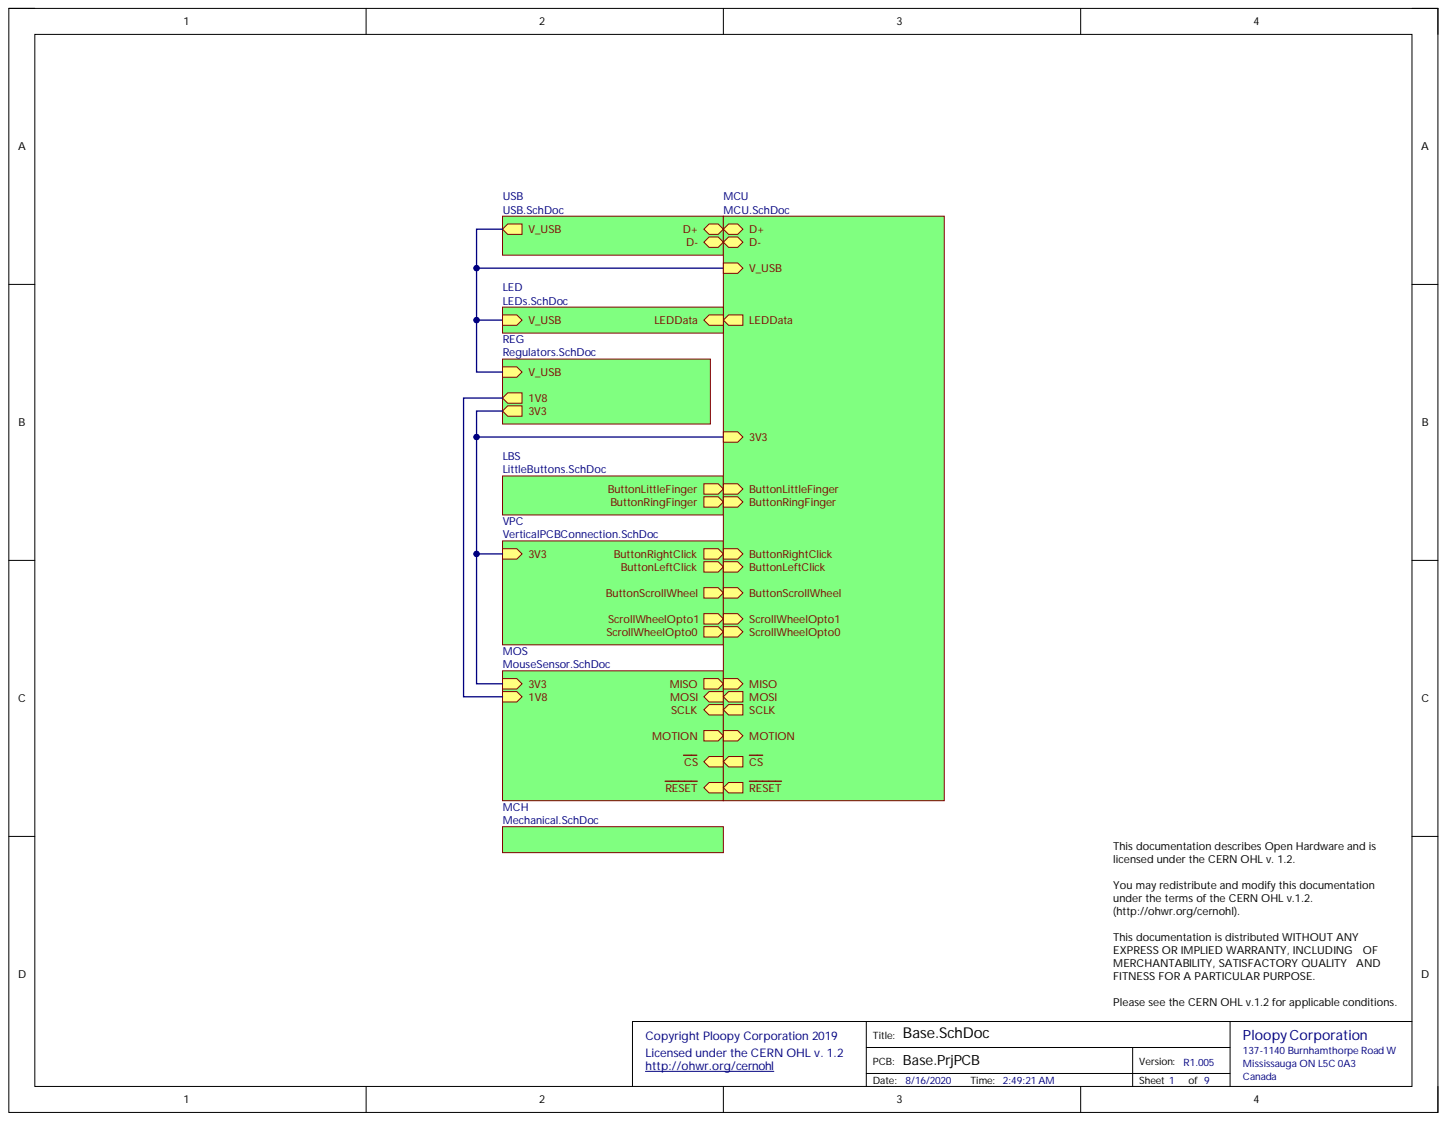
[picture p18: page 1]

This documentation describes Open Hardware and is
licensed under the CERN OHL v. 1.2.

You may redistribute and modify this documentation
under the terms of the CERN OHL v.1.2.
(http://ohwr.org/cernohl).

This documentation is distributed WITHOUT ANY
EXPRESS OR IMPLIED WARRANTY, INCLUDING OF
MERCHANTABILITY, SATISFACTORY QUALITY AND
FITNESS FOR A PARTICULAR PURPOSE.

Please see the CERN OHL v.1.2 for applicable conditions.

Copyright Ploopy Corporation 2019
Licensed under the CERN OHL v. 1.2
http://ohwr.org/cernohl

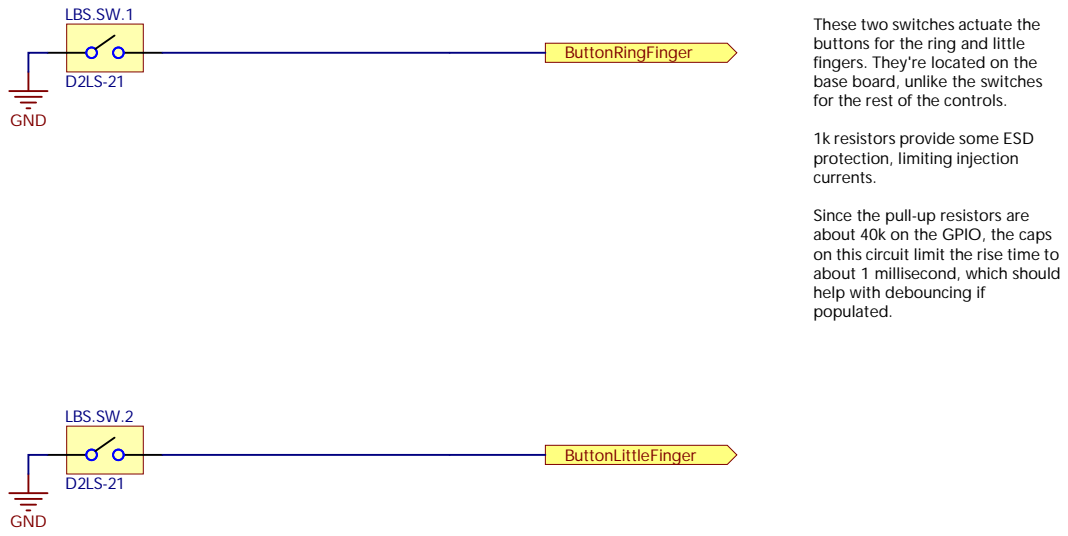
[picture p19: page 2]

These two switches actuate the
buttons for the ring and little
fingers. They're located on the
base board, unlike the switches
for the rest of the controls.

1k resistors provide some ESD
protection, limiting injection
currents.

Since the pull-up resistors are
about 40k on the GPIO, the caps
on this circuit limit the rise time to
about 1 millisecond, which should
help with debouncing if
populated.

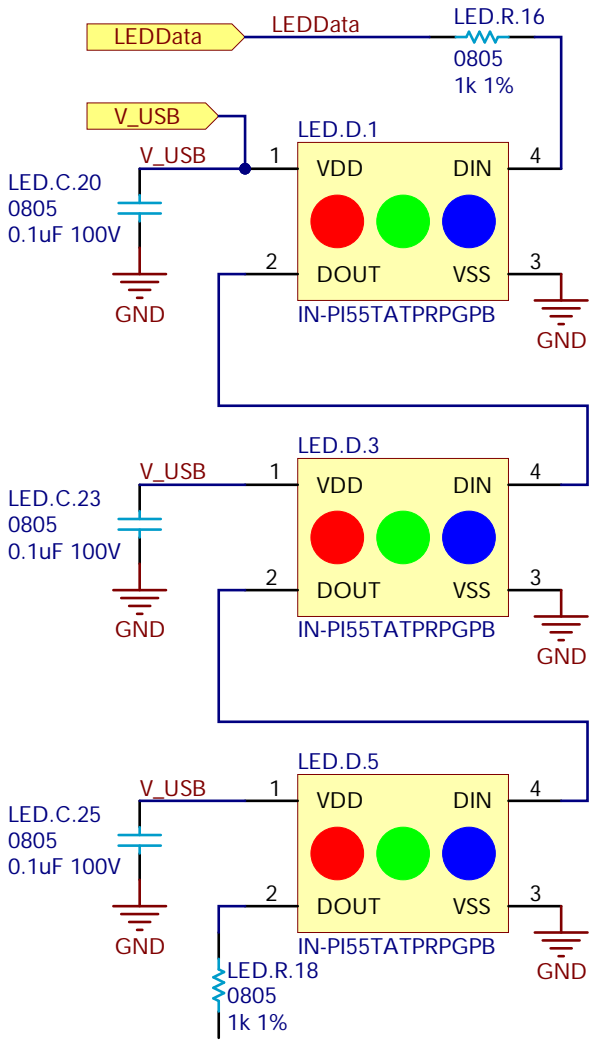
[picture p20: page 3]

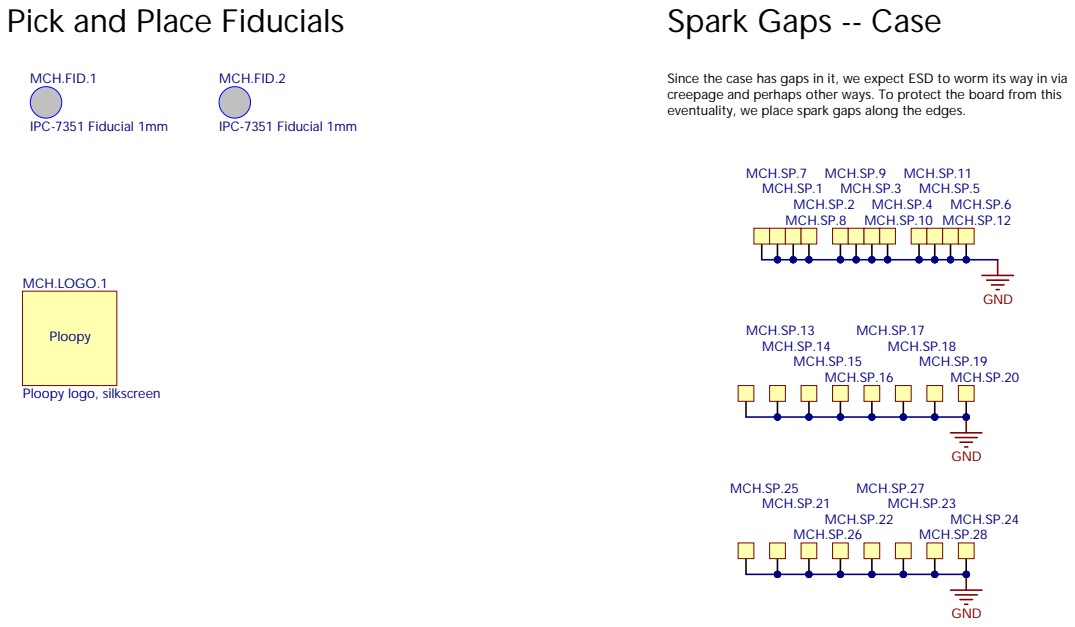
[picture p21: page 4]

Pick and Place Fiducials

Since the case has gaps in it, we expect ESD to worm its way in via
creepage and perhaps other ways. To protect the board from this
eventuality, we place spark gaps along the edges.

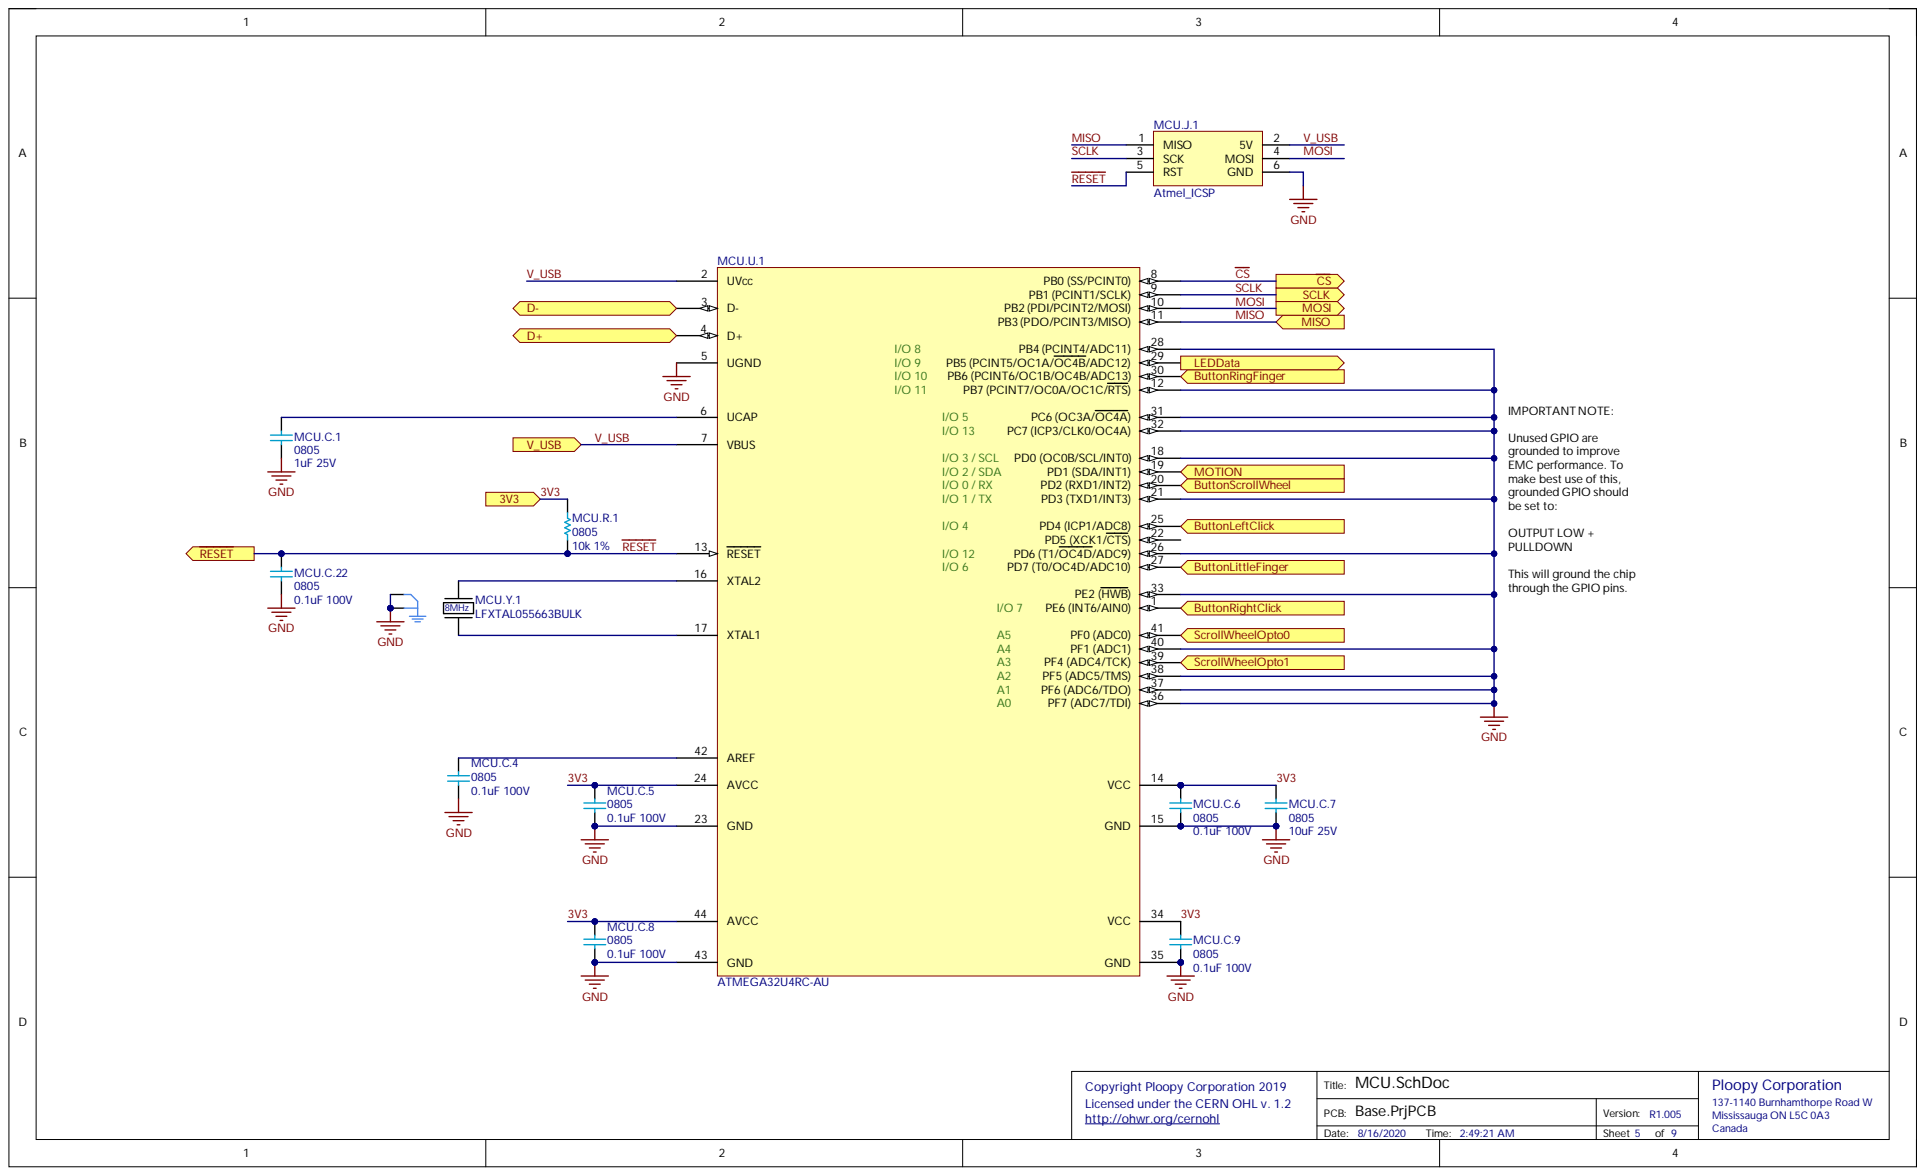
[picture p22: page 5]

Unused GPIO are
grounded to improve
EMC performance. To
make best use of this,
grounded GPIO should
be set to:

This will ground the chip
through the GPIO pins.

Copyright Ploopy Corporation 2019 Licensed under the CERN OHL v. 1.2 http://ohwr.org/cernohl | Title: MCU.SchDoc | Ploopy Corporation 137-1140 Burnhamthorpe Road W Mississauga ON L5C 0A3 Canada

PCB: Base.PrjPCB | Version: R1.005

Date: 8/16/2020 Time: 2:49:21 AM | Sheet 5 of 9

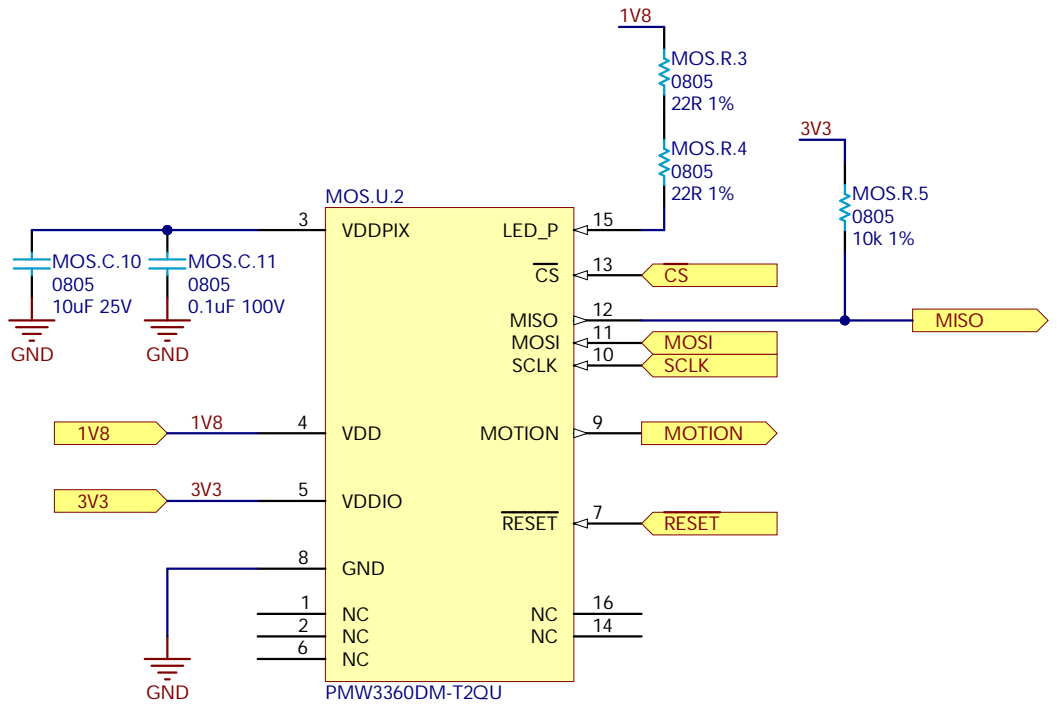
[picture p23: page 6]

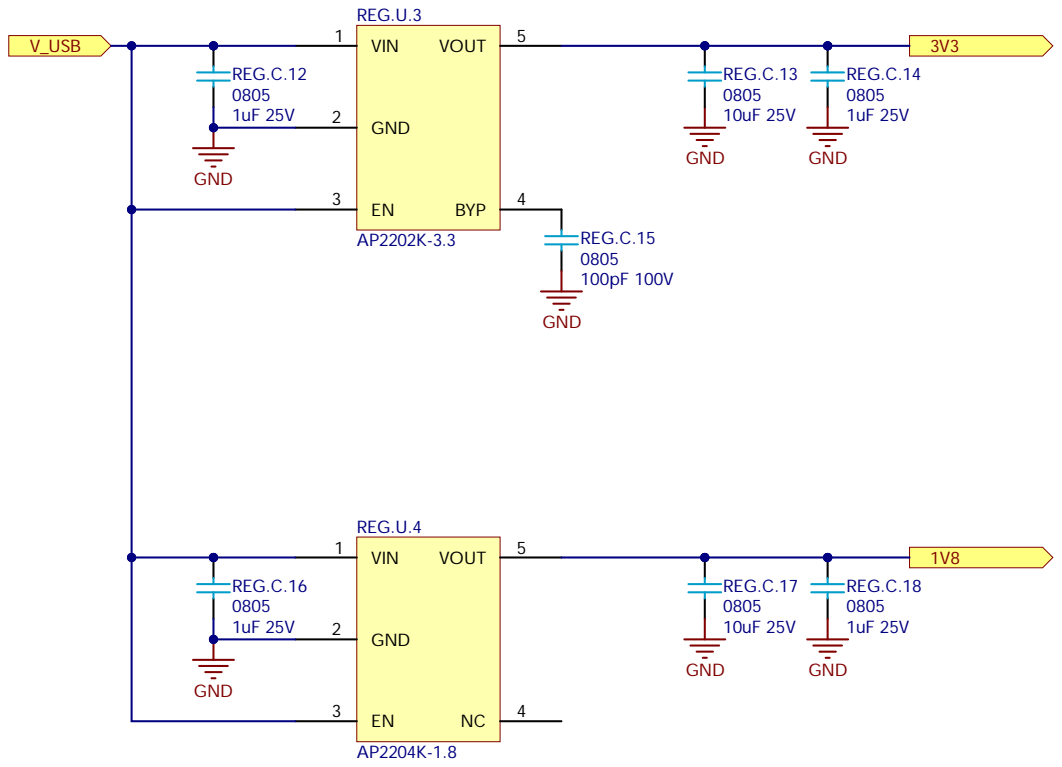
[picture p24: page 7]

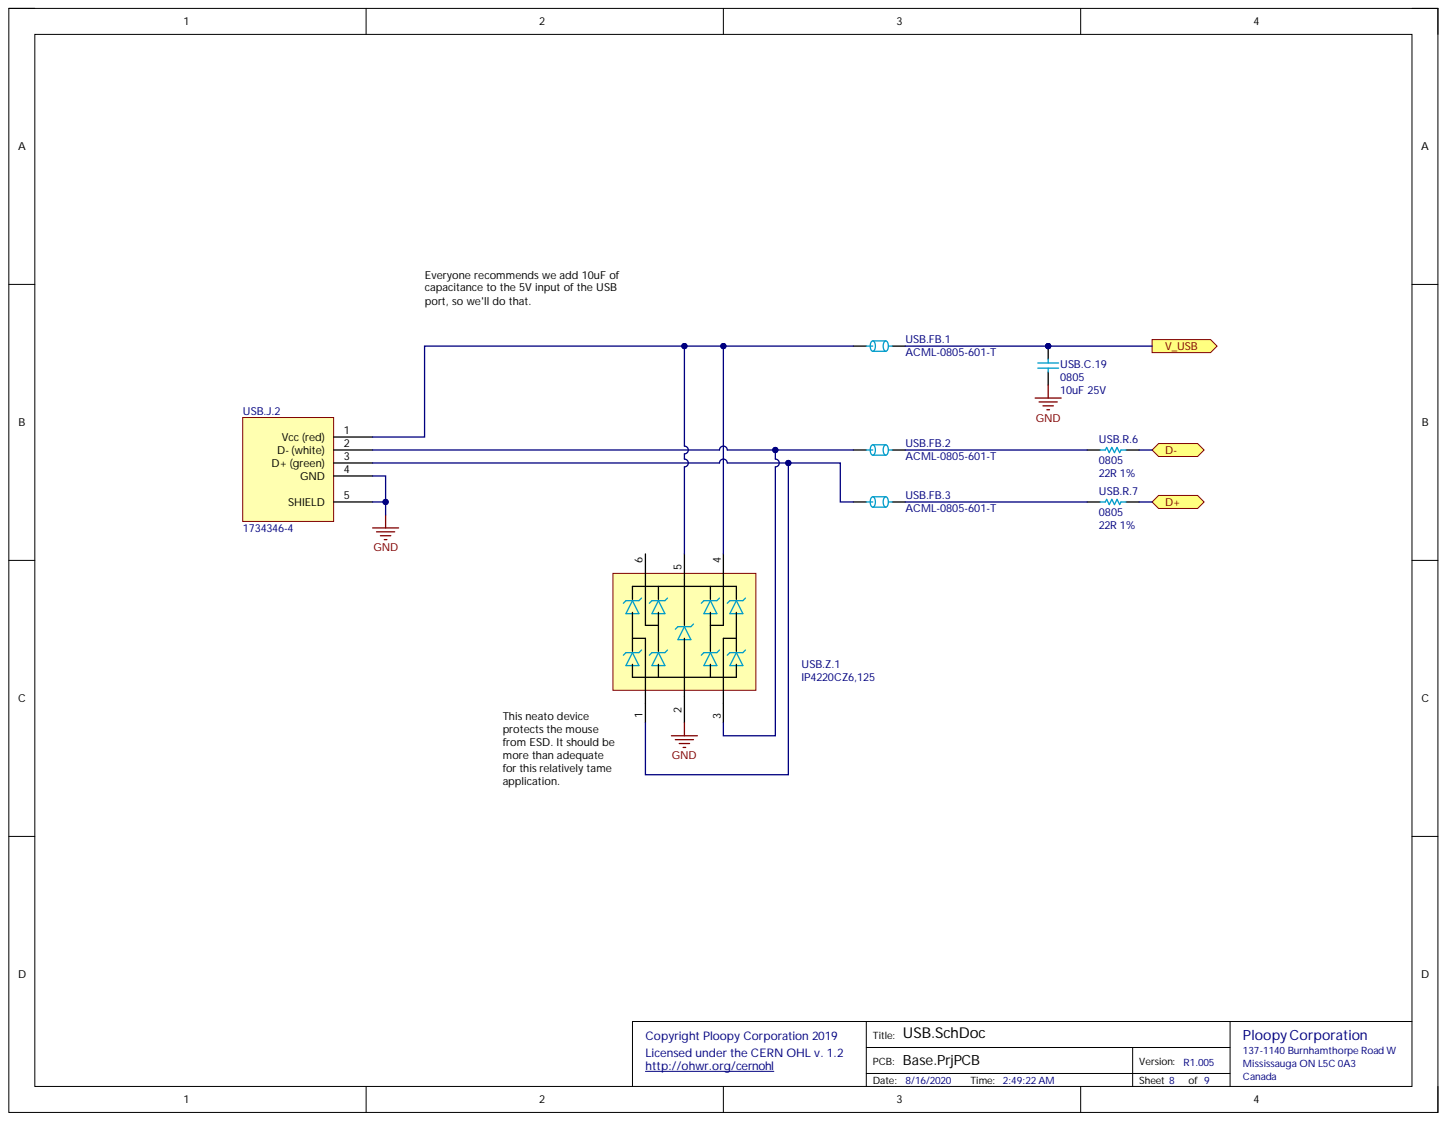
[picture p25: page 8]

Everyone recommends we add 10uF of
capacitance to the 5V input of the USB
port, so we'll do that.

This neato device
protects the mouse
from ESD. It should be
more than adequate
for this relatively tame
application.

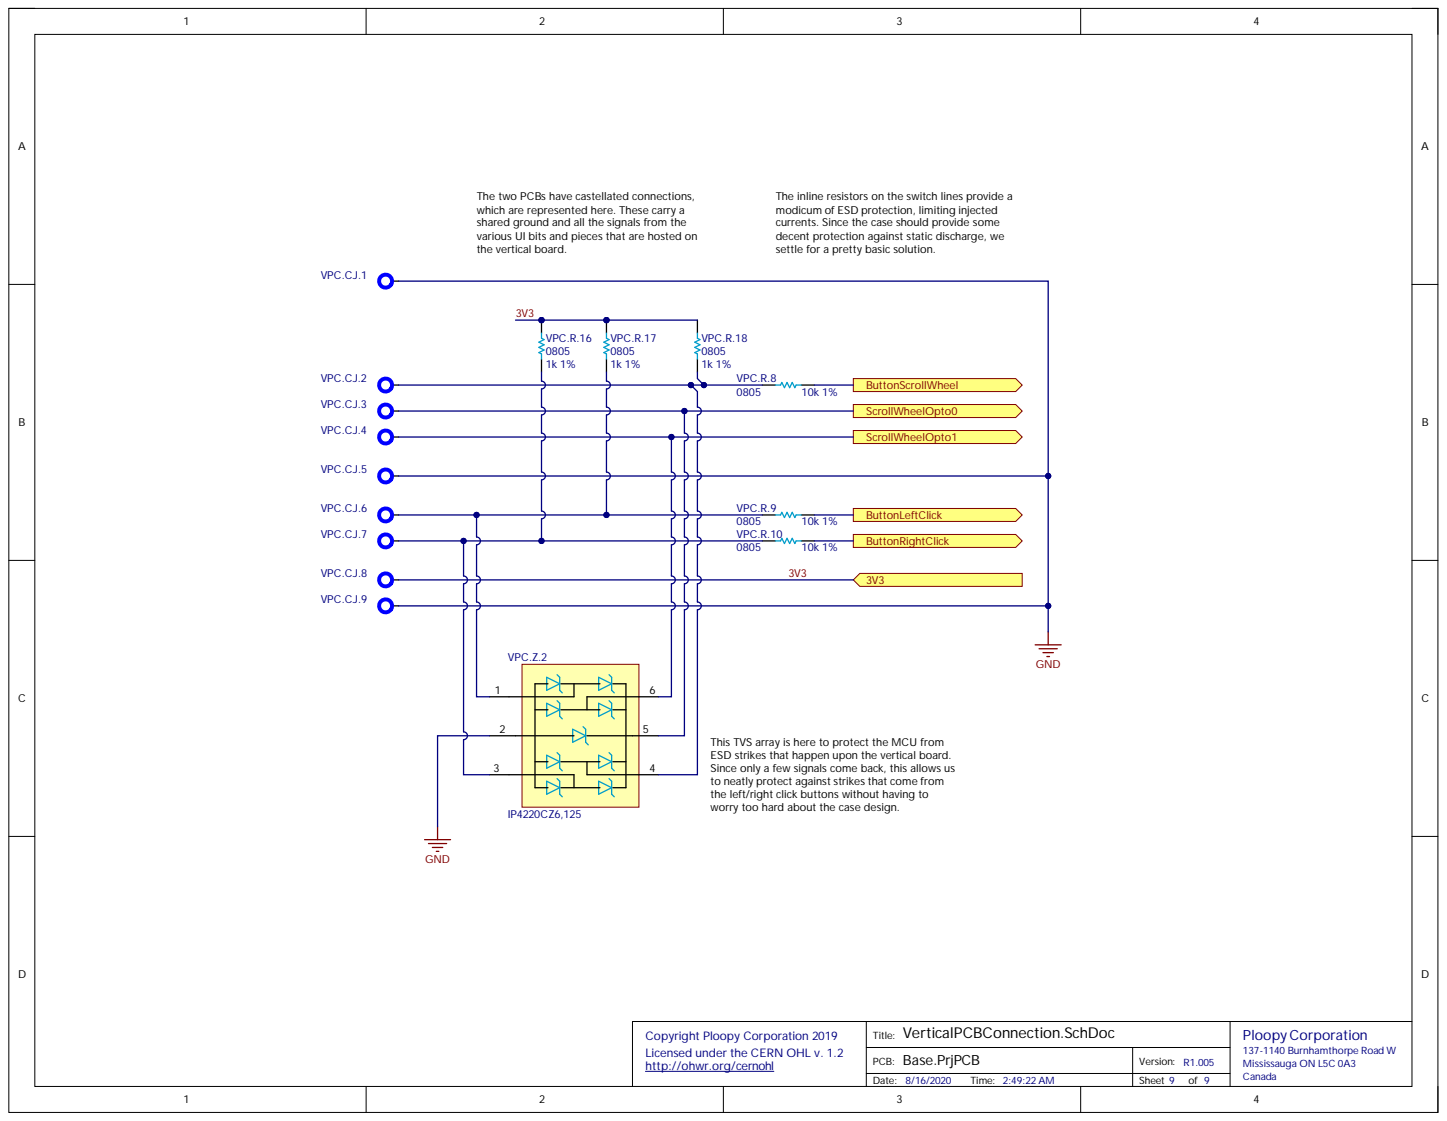
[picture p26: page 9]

The two PCBs have castellated connections,
which are represented here. These carry a
shared ground and all the signals from the
various UI bits and pieces that are hosted on
the vertical board.

The inline resistors on the switch lines provide a
modicum of ESD protection, limiting injected
currents. Since the case should provide some
decent protection against static discharge, we
settle for a pretty basic solution.

VPC.R.9 3V3
0805 VPC.R.10

This TVS array is here to protect the MCU from
ESD strikes that happen upon the vertical board.
Since only a few signals come back, this allows us
to neatly protect against strikes that come from
the left/right click buttons without having to
worry too hard about the case design.

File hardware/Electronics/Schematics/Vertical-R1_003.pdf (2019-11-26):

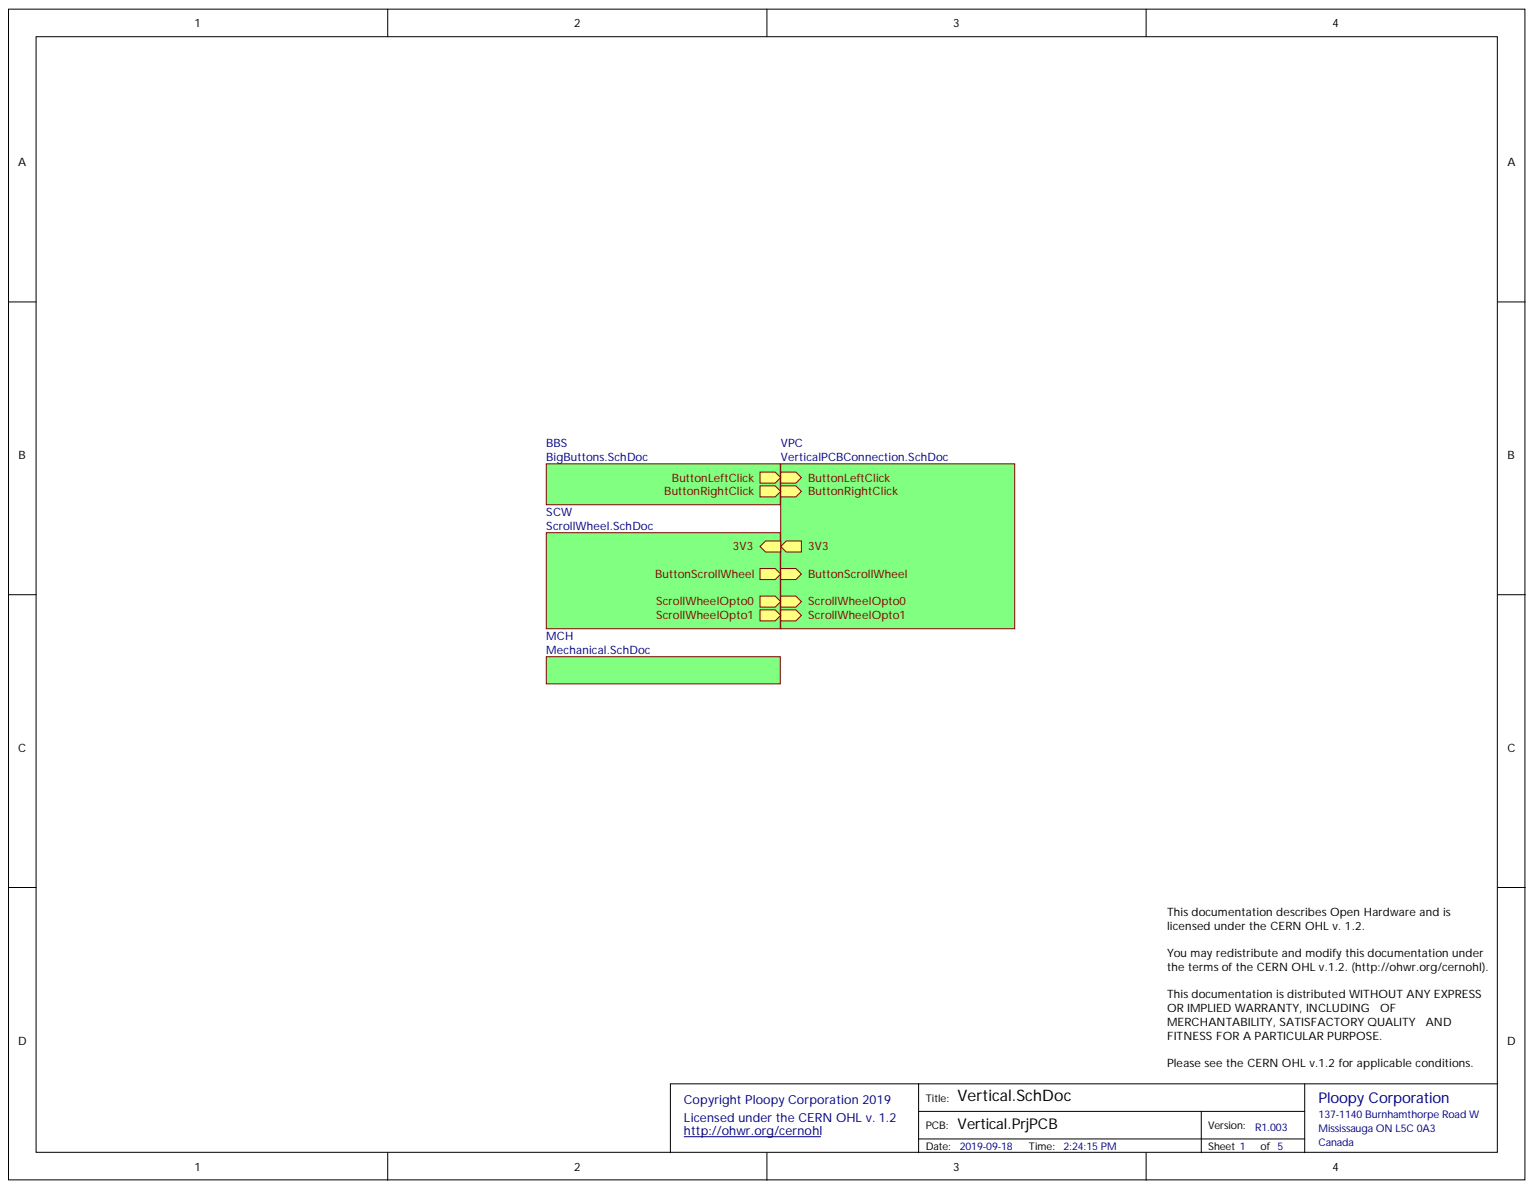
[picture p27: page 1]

This documentation describes Open Hardware and is
licensed under the CERN OHL v. 1.2.

You may redistribute and modify this documentation under
the terms of the CERN OHL v.1.2. (http://ohwr.org/cernohl).

This documentation is distributed WITHOUT ANY EXPRESS
OR IMPLIED WARRANTY, INCLUDING OF
MERCHANTABILITY, SATISFACTORY QUALITY AND
FITNESS FOR A PARTICULAR PURPOSE.

Please see the CERN OHL v.1.2 for applicable conditions.

Copyright Ploopy Corporation 2019 Licensed under the CERN OHL v. 1.2 http://ohwr.org/cernohl | Title: Vertical.SchDoc | Ploopy Corporation 137-1140 Burnhamthorpe Road W Mississauga ON L5C 0A3 Canada

PCB: Vertical.PrjPCB | Version: R1.003

Date: 2019-09-18 Time: 2:24:15 PM | Sheet of

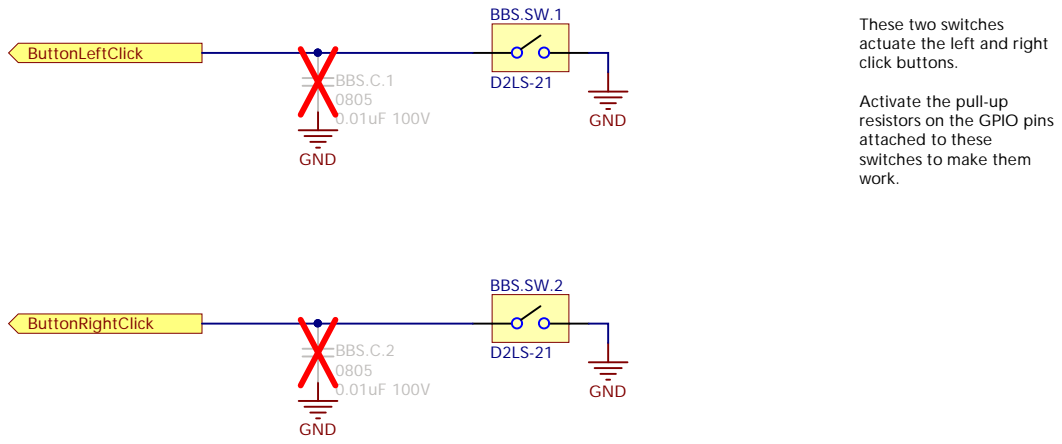
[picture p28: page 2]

These two switches
actuate the left and right
click buttons.

Activate the pull-up
resistors on the GPIO pins
attached to these
switches to make them
work.

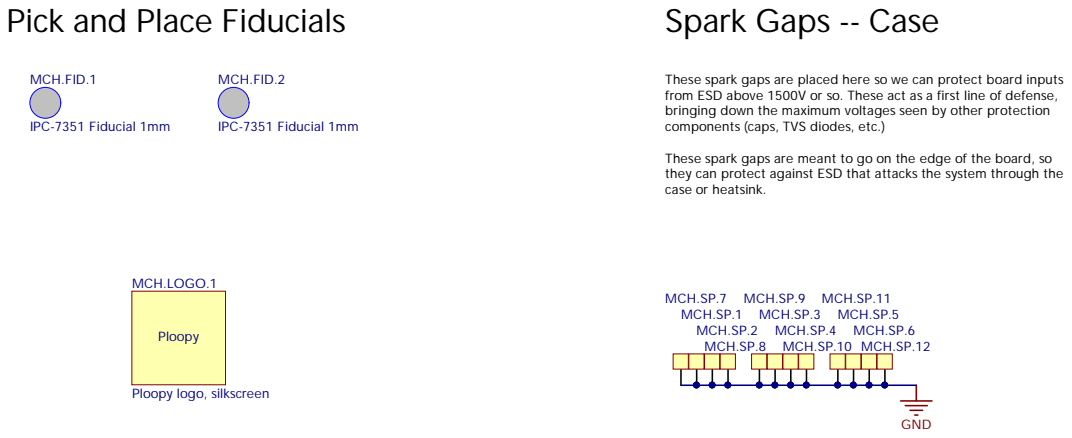
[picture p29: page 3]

Pick and Place Fiducials

These spark gaps are placed here so we can protect board inputs
from ESD above 1500V or so. These act as a first line of defense,
bringing down the maximum voltages seen by other protection
components (caps, TVS diodes, etc.)

These spark gaps are meant to go on the edge of the board, so
they can protect against ESD that attacks the system through the
case or heatsink.


The button is pretty straightforward: when the
scroll wheel gets pressed, the button is
pressed.

To make this work, the pull-up resistor on the
GPIO pin it's attached to needs to be
activated.

The scroll wheel mechanism is a 2-bit optical
encoder. The light paths are spaced 1.5
periods over the encoder wheel holes, which
should allow for the detection of the rotation
direction as well as the rotation itself.

Two IR LEDs are used as light sources; the light
from these is obstructed by the encoder wheel
built into the scroll wheel mechanism. Two
phototransistors are used to detect when the
light is blocked/not blocked by the wheel.

Typical LED forward voltage is 1.3V @20mA.
To achieve this current level with a 3.3V
supply, we'll use a 100R resistor, which is very
convenient.

At this power level, the output should be
approx 2.3mW/sr.

Since the light path distance is about 12mm,
that works out to about 2mW/cm^2, though
the actual delivered power will be lower due to
the vagaries of the obstructions in the
mechanism.

With this amount of light (and accounting for
the fact that we'll probably lose a lot of it
along the way), we are expecting 1-3mA out of
the phototransistor (see figure 6 of the
datasheet), so we size the biasing resistor
accordingly to produce a useful signal.


The two PCBs have
castellated connections,
which are represented here.
These carry a shared ground
and all the signals from the
various UI bits and pieces
that are hosted on the
vertical board.


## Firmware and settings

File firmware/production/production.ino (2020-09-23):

/*
 * Copyright (c) 2019, Ploopy Corporation, a Canadian federal corporation.
 *
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
 * You should have received a copy of the GNU General Public License
 * along with this program; if not, write to the Free Software
 * Foundation, Inc.
 * 51 Franklin St, Fifth Floor, Boston, MA  02110-1301  USA
 */

#include <SPI.h>
#include <avr/pgmspace.h>
#include <avr/wdt.h>
#include "AdvMouse.h"
#include "Scroller.h"

// Max recommended is 4,000,000, since clock speed is 8MHz.
// If lower, it should be by factors of 1/2.
static const int SPIMAXIMUMSPEED = 2000000;

static const int CPI = 1200;
static const int DEBOUNCE = 10; // ms
static const int SCROLL_DEBOUNCE = 100; // ms
static const int SCROLL_BUTT_DEBOUNCE = 100; // ms

static const int8_t ROTATIONAL_TRANSFORM_ANGLE = 20;

static const int MOUSE_LEFT_PIN = 4;
static const int MOUSE_RIGHT_PIN = 7;
static const int MOUSE_MIDDLE_PIN = 0;
static const int MOUSE_BACK_PIN = 10;
static const int MOUSE_FORWARD_PIN = 6;

// For info, see https://forum.arduino.cc/index.php?topic=241369.0
static const int SENSOR_CS = 17;

static const int OPT_ENC_PIN1 = A3;
static const int OPT_ENC_PIN2 = A5;

static const byte MOTION = 0x02;
static const byte DELTA_X_L = 0x03;
static const byte DELTA_X_H = 0x04;
static const byte DELTA_Y_L = 0x05;
static const byte DELTA_Y_H = 0x06;
static const byte CONFIG1 = 0x0F;
static const byte CONFIG2 = 0x10;
static const byte ANGLE_TUNE = 0x11;
static const byte SROM_ENABLE = 0x13;
static const byte SROM_ID = 0x2A;
static const byte POWER_UP_RESET = 0x3A;
static const byte SHUTDOWN = 0x3B;
static const byte MOTION_BURST = 0x50;
static const byte SROM_LOAD_BURST = 0x62;

boolean debugMode = false;
boolean wdtMode = false;

int buttonPin[5] = { MOUSE_LEFT_PIN, MOUSE_RIGHT_PIN, MOUSE_MIDDLE_PIN, MOUSE_BACK_PIN, MOUSE_FORWARD_PIN };
bool buttonState[5] = { false, false, false, false, false };
uint8_t buttonBuffer[5] = { 0xFF, 0xFF, 0xFF, 0xFF, 0xFF };
char buttonKey[5] = { MOUSE_LEFT, MOUSE_RIGHT, MOUSE_MIDDLE, MOUSE_BACK, MOUSE_FORWARD };

bool initComplete = false;

int16_t dx;
int16_t dy;

unsigned long lastTS;
unsigned long lastButtonCheck = 0;

unsigned long lastScroll = 0;

unsigned long middleClickRelease = 0;

static Scroller scroller;

extern const unsigned short firmware_length;
extern const unsigned char firmware_data[];

void setup() {
  if (wdtMode) {
    setupWDT();
  }

  if (debugMode) {
    Serial.begin(9600);
  }

  // Startup delay. This sometimes prevents a USB handshake lockup.
  delay(1000);

  setupPins();

  SPI.begin();
  SPI.setDataMode(SPI_MODE3);
  SPI.setBitOrder(MSBFIRST);

  initialisePMW3360();

  dx = 0;
  dy = 0;

  delay(1000);

  initComplete = true;

  lastTS = micros();

  AdvMouse.begin();

  if (debugMode) {
    Serial.println(F("end setup"));
  }
}

void setupWDT() {
  /* IMPORTANT NOTE!
   * THIS MUST BE THE FIRST THING THAT RUNS IN SETUP()! If it isn't, there's
   * a good chance the Arduino will enter an unstable state, and it's entirely
   * possible that you can permanently brick your MCU!
   */

  cli();

  // Clear the watchdog reset flag
  MCUSR &= ~(1 << WDRF);

  // Enter watchdog configuration mode
  WDTCSR |= (1 << WDCE) |
            (1 << WDE);

  // WDIE needs to be included, or else this doesn't work.
  WDTCSR = (1 << WDIE) |
           (1 << WDE) |
           (1 << WDP3) |
           (0 << WDP2) |
           (0 << WDP1) |
           (0 << WDP0);

  sei();
}

void setupPins() {
  pinMode(SENSOR_CS, OUTPUT);
  pinMode(MOUSE_LEFT_PIN, INPUT_PULLUP);
  pinMode(MOUSE_RIGHT_PIN, INPUT_PULLUP);
  pinMode(MOUSE_MIDDLE_PIN, INPUT_PULLUP);
  pinMode(MOUSE_BACK_PIN, INPUT_PULLUP);
  pinMode(MOUSE_FORWARD_PIN, INPUT_PULLUP);

  pinMode(OPT_ENC_PIN1, INPUT);
  pinMode(OPT_ENC_PIN2, INPUT);

  /* Ground all output pins connected to ground. This provides additional
   * pathways to ground. If you're messing with this, know this: driving ANY
   * of these pins high will cause a short. On the MCU. Ka-blooey.
   */
  pinMode(1, OUTPUT);
  pinMode(2, OUTPUT);
  pinMode(8, OUTPUT);
  pinMode(11, OUTPUT);
  pinMode(12, OUTPUT);
  pinMode(13, OUTPUT);
  pinMode(A0, OUTPUT);
  pinMode(A1, OUTPUT);
  pinMode(A2, OUTPUT);
  pinMode(A4, OUTPUT);
  digitalWrite(1, LOW);
  digitalWrite(2, LOW);
  digitalWrite(8, LOW);
  digitalWrite(11, LOW);
  digitalWrite(12, LOW);
  digitalWrite(13, LOW);
  digitalWrite(A0, LOW);
  digitalWrite(A1, LOW);
  digitalWrite(A2, LOW);
  digitalWrite(A4, LOW);
}

void adnsComBegin() {
  digitalWrite(SENSOR_CS, LOW);
}

void adnsComEnd() {
  digitalWrite(SENSOR_CS, HIGH);
}

byte adnsReadReg(byte reg_addr) {
  adnsComBegin();

  // send adress of the register, with MSBit = 0 to indicate it's a read
  SPI.transfer(reg_addr & 0x7f);
  delayMicroseconds(35); // tSRAD
  byte data = SPI.transfer(0);

  // tSCLK-SENSOR_CS for read operation is 120ns
  delayMicroseconds(1);
  adnsComEnd();
  // tSRW/tSRR (=20us) minus tSCLK-SENSOR_CS
  delayMicroseconds(19);

  return data;
}

void adnsWriteReg(byte reg_addr, byte data) {
  adnsComBegin();

  // send adress of the register, with MSBit = 1 to indicate it's a write
  SPI.transfer(reg_addr | 0x80);
  SPI.transfer(data);

  // tSCLK-SENSOR_CS for write operation
  delayMicroseconds(20);
  adnsComEnd();
  // tSWW/tSWR (=120us) minus tSCLK-SENSOR_CS.
  // Could be shortened, but this looks like a safe lower-bound.
  delayMicroseconds(100);
}

void setCPI(int cpi) {
  int cpival = constrain((cpi / 100) - 1, 0, 0x77); // limits to 0--119

  adnsComBegin();
  adnsWriteReg(CONFIG1, cpival);
  adnsComEnd();

  if (debugMode) {
    Serial.print(F("Got "));
    Serial.println(cpi);
    Serial.print(F("Set cpi to "));
    Serial.println((cpival + 1) * 100);
  }
}

void initialisePMW3360(void) {
  if (debugMode) {
    Serial.println(F("Initialising PMW3360"));
  }

  // Hard reset. Start by ensuring that the serial port is reset.
  adnsComEnd();
  adnsComBegin();
  adnsComEnd();

  // SHUTDOWN the PMW3360, in case the microcontroller reset but the sensor didn't.
  adnsWriteReg(SHUTDOWN, 0xb6);
  delay(300);

  // Drop and raise SENSOR_CS to reset the spi port
  adnsComBegin();
  delayMicroseconds(40);
  adnsComEnd();
  delayMicroseconds(40);

  // Force a reset of the PMW3360.
  adnsWriteReg(POWER_UP_RESET, 0x5a);
  delay(50);

  // Read registers 0x02 through 0x06 (and discard the data)
  adnsReadReg(MOTION);
  adnsReadReg(DELTA_X_L);
  adnsReadReg(DELTA_X_H);
  adnsReadReg(DELTA_Y_L);
  adnsReadReg(DELTA_Y_H);

  if (debugMode) {
    Serial.println(F("Uploading firmware to PMW3360"));
  }

  // Write 0 to Rest_En bit of CONFIG2 register to disable Rest mode.
  adnsWriteReg(CONFIG2, 0x00);

  // Rotate the x and y results, since the sensor isn't quite squared up in
  // the enclosure.
  // Sensor rotates up to +/-30 degrees
  adnsWriteReg(ANGLE_TUNE, constrain(ROTATIONAL_TRANSFORM_ANGLE, -30, 30));

  // write 0x1d in SROM_enable reg for initializing
  adnsWriteReg(SROM_ENABLE, 0x1d);

  // wait for more than one frame period
  // assume that the frame rate is as low as 100fps, even if it should never be that low
  delay(10);

  // write 0x18 to SROM_enable to start SROM download
  adnsWriteReg(SROM_ENABLE, 0x18);

  // write burst destination adress
  adnsComBegin();
  SPI.transfer(SROM_LOAD_BURST | 0x80);
  delayMicroseconds(15);

  unsigned char c;
  for (int i = 0; i < firmware_length; i++) {
    c = (unsigned char) pgm_read_byte(firmware_data + i);
    SPI.transfer(c);
    delayMicroseconds(15);
  }

  // Read the SROM_ID register to verify the ID before any other register reads or writes.
  adnsReadReg(SROM_ID);

  // Write 0x00 (rest disable) to CONFIG2 register for wired mouse.
  // (If this were a wireless design, it'd be 0x20.)
  adnsWriteReg(CONFIG2, 0x00);

  adnsComEnd();

  if (debugMode) {
    Serial.println(F("Firmware successfully written to PMW3360"));
  }

  delay(10);

  setCPI(CPI);

  // start burst mode
  adnsWriteReg(MOTION_BURST, 0x00);

  if (debugMode) {
    Serial.println(F("PMW3360 successfully initialized"));
  }
}


void checkButtonState() {
  if (!initComplete)
    return;

  unsigned long elapsed = micros() - lastButtonCheck;

  // Update at a period of 1/8 of the DEBOUNCE time
  if (elapsed < (DEBOUNCE * 1000UL / 8)) {
    return;
  }

  lastButtonCheck = micros();

  // Fast debounce (works with 0 latency most of the time)
  for (int i = 0; i < 5; i++) {
    int curButtonState = digitalRead(buttonPin[i]);
    buttonBuffer[i] = buttonBuffer[i] << 1 | curButtonState;

    if (!buttonState[i] && buttonBuffer[i] == 0xFE) {
      // First time the button press is being registered.
      AdvMouse.press_(buttonKey[i]);
      buttonState[i] = true;
    } else if ((buttonState[i] && buttonBuffer[i] == 0x01) ||
               (buttonState[i] && buttonBuffer[i] == 0xFF)) {
      // Either the button is being released, or the debounce time elapsed.
      AdvMouse.release_(buttonKey[i]);
      buttonState[i] = false;

      if (buttonPin[i] == MOUSE_MIDDLE_PIN) {
        middleClickRelease = micros();
      }
    }
  }
}

signed char moveWheel() {
  // If the mouse wheel was just released, do not scroll.
  unsigned long elapsed = micros() - middleClickRelease;
  if (elapsed < SCROLL_BUTT_DEBOUNCE) {
    return 0;
  }

  // Limit the number of scrolls per unit time.
  elapsed = micros() - lastScroll;
  if (elapsed < SCROLL_DEBOUNCE) {
    return 0;
  }

  // Don't scroll if the middle button is depressed.
  int middleButtonPin = digitalRead(MOUSE_MIDDLE_PIN);
  if (middleButtonPin == LOW) {
    return 0;
  }

  lastScroll = micros();

  int d1 = analogRead(OPT_ENC_PIN1);
  int d2 = analogRead(OPT_ENC_PIN2);

  if (debugMode) {
    scroller.debug();
    Serial.print(F(", d1: "));
    Serial.print(d1);
    Serial.print(F(", d2: "));
    Serial.println(d2);
  }

  return scroller.scroll(d2, d1);
}

void loop() {
  if (wdtMode) {
    wdt_reset();
  }

  byte burstBuffer[12];
  unsigned long curTime = micros();
  unsigned long elapsed = curTime - lastTS;

  checkButtonState();

  // polling interval : more than > 0.5 ms.
  if (elapsed >= 1000) {
    adnsComBegin();
    SPI.beginTransaction(SPISettings(SPIMAXIMUMSPEED, MSBFIRST, SPI_MODE3));

    SPI.transfer(MOTION_BURST);
    // Wait for tSRAD
    delayMicroseconds(35);

    // read burst buffer
    SPI.transfer(burstBuffer, 12);
    // tSCLK-SENSOR_CS for read operation is 120ns
    delayMicroseconds(1);

    SPI.endTransaction();

    int motion = (burstBuffer[0] & 0x80) > 0;

    int xl = burstBuffer[2];
    int xh = burstBuffer[3];
    int yl = burstBuffer[4];
    int yh = burstBuffer[5];

    int x = xh << 8 | xl;
    int y = yh << 8 | yl;

    dx -= x;
    dy += y;

    adnsComEnd();

    signed char wheel = moveWheel();

    // update only if a movement is detected.
    if (AdvMouse.needSendReport() || motion || wheel != 0) {
      AdvMouse.move(dx, dy, wheel);
      dx = 0;
      dy = 0;
    }

    lastTS = curTime;
  }
}

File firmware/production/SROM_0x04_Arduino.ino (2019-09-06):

/*
 * Copyright (c) 2019 Sunjun Kim
 *
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
 * You should have received a copy of the GNU General Public License
 * along with this program; if not, write to the Free Software
 * Foundation, Inc.
 * 51 Franklin St, Fifth Floor, Boston, MA  02110-1301  USA
 */



// This is the firmware that is uploaded to the PMW3360 each time the mouse starts up.
// Don't mess with this. Just...just trust me. Don't do it.

#include <avr/pgmspace.h>

const unsigned short firmware_length = 4094;

const unsigned char firmware_data[] PROGMEM = {
0x01, 0x04, 0x8e, 0x96, 0x6e, 0x77, 0x3e, 0xfe, 0x7e, 0x5f, 0x1d, 0xb8, 0xf2, 0x66, 0x4e, 
0xff, 0x5d, 0x19, 0xb0, 0xc2, 0x04, 0x69, 0x54, 0x2a, 0xd6, 0x2e, 0xbf, 0xdd, 0x19, 0xb0, 
0xc3, 0xe5, 0x29, 0xb1, 0xe0, 0x23, 0xa5, 0xa9, 0xb1, 0xc1, 0x00, 0x82, 0x67, 0x4c, 0x1a, 
0x97, 0x8d, 0x79, 0x51, 0x20, 0xc7, 0x06, 0x8e, 0x7c, 0x7c, 0x7a, 0x76, 0x4f, 0xfd, 0x59, 
0x30, 0xe2, 0x46, 0x0e, 0x9e, 0xbe, 0xdf, 0x1d, 0x99, 0x91, 0xa0, 0xa5, 0xa1, 0xa9, 0xd0, 
0x22, 0xc6, 0xef, 0x5c, 0x1b, 0x95, 0x89, 0x90, 0xa2, 0xa7, 0xcc, 0xfb, 0x55, 0x28, 0xb3, 
0xe4, 0x4a, 0xf7, 0x6c, 0x3b, 0xf4, 0x6a, 0x56, 0x2e, 0xde, 0x1f, 0x9d, 0xb8, 0xd3, 0x05, 
0x88, 0x92, 0xa6, 0xce, 0x1e, 0xbe, 0xdf, 0x1d, 0x99, 0xb0, 0xe2, 0x46, 0xef, 0x5c, 0x07, 
0x11, 0x5d, 0x98, 0x0b, 0x9d, 0x94, 0x97, 0xee, 0x4e, 0x45, 0x33, 0x6b, 0x44, 0xc7, 0x29, 
0x56, 0x27, 0x30, 0xc6, 0xa7, 0xd5, 0xf2, 0x56, 0xdf, 0xb4, 0x38, 0x62, 0xcb, 0xa0, 0xb6, 
0xe3, 0x0f, 0x84, 0x06, 0x24, 0x05, 0x65, 0x6f, 0x76, 0x89, 0xb5, 0x77, 0x41, 0x27, 0x82, 
0x66, 0x65, 0x82, 0xcc, 0xd5, 0xe6, 0x20, 0xd5, 0x27, 0x17, 0xc5, 0xf8, 0x03, 0x23, 0x7c, 
0x5f, 0x64, 0xa5, 0x1d, 0xc1, 0xd6, 0x36, 0xcb, 0x4c, 0xd4, 0xdb, 0x66, 0xd7, 0x8b, 0xb1, 
0x99, 0x7e, 0x6f, 0x4c, 0x36, 0x40, 0x06, 0xd6, 0xeb, 0xd7, 0xa2, 0xe4, 0xf4, 0x95, 0x51, 
0x5a, 0x54, 0x96, 0xd5, 0x53, 0x44, 0xd7, 0x8c, 0xe0, 0xb9, 0x40, 0x68, 0xd2, 0x18, 0xe9, 
0xdd, 0x9a, 0x23, 0x92, 0x48, 0xee, 0x7f, 0x43, 0xaf, 0xea, 0x77, 0x38, 0x84, 0x8c, 0x0a, 
0x72, 0xaf, 0x69, 0xf8, 0xdd, 0xf1, 0x24, 0x83, 0xa3, 0xf8, 0x4a, 0xbf, 0xf5, 0x94, 0x13, 
0xdb, 0xbb, 0xd8, 0xb4, 0xb3, 0xa0, 0xfb, 0x45, 0x50, 0x60, 0x30, 0x59, 0x12, 0x31, 0x71, 
0xa2, 0xd3, 0x13, 0xe7, 0xfa, 0xe7, 0xce, 0x0f, 0x63, 0x15, 0x0b, 0x6b, 0x94, 0xbb, 0x37, 
0x83, 0x26, 0x05, 0x9d, 0xfb, 0x46, 0x92, 0xfc, 0x0a, 0x15, 0xd1, 0x0d, 0x73, 0x92, 0xd6, 
0x8c, 0x1b, 0x8c, 0xb8, 0x55, 0x8a, 0xce, 0xbd, 0xfe, 0x8e, 0xfc, 0xed, 0x09, 0x12, 0x83, 
0x91, 0x82, 0x51, 0x31, 0x23, 0xfb, 0xb4, 0x0c, 0x76, 0xad, 0x7c, 0xd9, 0xb4, 0x4b, 0xb2, 
0x67, 0x14, 0x09, 0x9c, 0x7f, 0x0c, 0x18, 0xba, 0x3b, 0xd6, 0x8e, 0x14, 0x2a, 0xe4, 0x1b, 
0x52, 0x9f, 0x2b, 0x7d, 0xe1, 0xfb, 0x6a, 0x33, 0x02, 0xfa, 0xac, 0x5a, 0xf2, 0x3e, 0x88, 
0x7e, 0xae, 0xd1, 0xf3, 0x78, 0xe8, 0x05, 0xd1, 0xe3, 0xdc, 0x21, 0xf6, 0xe1, 0x9a, 0xbd, 
0x17, 0x0e, 0xd9, 0x46, 0x9b, 0x88, 0x03, 0xea, 0xf6, 0x66, 0xbe, 0x0e, 0x1b, 0x50, 0x49, 
0x96, 0x40, 0x97, 0xf1, 0xf1, 0xe4, 0x80, 0xa6, 0x6e, 0xe8, 0x77, 0x34, 0xbf, 0x29, 0x40, 
0x44, 0xc2, 0xff, 0x4e, 0x98, 0xd3, 0x9c, 0xa3, 0x32, 0x2b, 0x76, 0x51, 0x04, 0x09, 0xe7, 
0xa9, 0xd1, 0xa6, 0x32, 0xb1, 0x23, 0x53, 0xe2, 0x47, 0xab, 0xd6, 0xf5, 0x69, 0x5c, 0x3e, 
0x5f, 0xfa, 0xae, 0x45, 0x20, 0xe5, 0xd2, 0x44, 0xff, 0x39, 0x32, 0x6d, 0xfd, 0x27, 0x57, 
0x5c, 0xfd, 0xf0, 0xde, 0xc1, 0xb5, 0x99, 0xe5, 0xf5, 0x1c, 0x77, 0x01, 0x75, 0xc5, 0x6d, 
0x58, 0x92, 0xf2, 0xb2, 0x47, 0x00, 0x01, 0x26, 0x96, 0x7a, 0x30, 0xff, 0xb7, 0xf0, 0xef, 
0x77, 0xc1, 0x8a, 0x5d, 0xdc, 0xc0, 0xd1, 0x29, 0x30, 0x1e, 0x77, 0x38, 0x7a, 0x94, 0xf1, 
0xb8, 0x7a, 0x7e, 0xef, 0xa4, 0xd1, 0xac, 0x31, 0x4a, 0xf2, 0x5d, 0x64, 0x3d, 0xb2, 0xe2, 
0xf0, 0x08, 0x99, 0xfc, 0x70, 0xee, 0x24, 0xa7, 0x7e, 0xee, 0x1e, 0x20, 0x69, 0x7d, 0x44, 
0xbf, 0x87, 0x42, 0xdf, 0x88, 0x3b, 0x0c, 0xda, 0x42, 0xc9, 0x04, 0xf9, 0x45, 0x50, 0xfc, 
0x83, 0x8f, 0x11, 0x6a, 0x72, 0xbc, 0x99, 0x95, 0xf0, 0xac, 0x3d, 0xa7, 0x3b, 0xcd, 0x1c, 
0xe2, 0x88, 0x79, 0x37, 0x11, 0x5f, 0x39, 0x89, 0x95, 0x0a, 0x16, 0x84, 0x7a, 0xf6, 0x8a, 
0xa4, 0x28, 0xe4, 0xed, 0x83, 0x80, 0x3b, 0xb1, 0x23, 0xa5, 0x03, 0x10, 0xf4, 0x66, 0xea, 
0xbb, 0x0c, 0x0f, 0xc5, 0xec, 0x6c, 0x69, 0xc5, 0xd3, 0x24, 0xab, 0xd4, 0x2a, 0xb7, 0x99, 
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

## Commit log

2019-11-26 R1.003 electronics design files.
    [Base.PcbDoc, Base.PrjPCB, Base.SchDoc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]
2019-11-26 R1.003 schematics in PDF form and Gerbers for sending to a PCB house.
2019-11-26 Rev A 3D printed parts.
    [Little Buttons.stp, MTBE-003.stp, MTBE-004.stp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]
2019-11-26 added electricals and mechanicals
    [PCB Anchor.stl, PCB Anchor.stp, Primary Buttons.stl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]
2019-11-26 Make use of PMW3360's Angle_Tune register
    Sensor can rotate its output up to +/-30 degrees.
2019-11-26 Change polling interval to a regular 1ms
    Motion burst + analog reads takes around 408us.
    The total 408us + 870us wait doesn't seem necessary.
    [production.ino]
2019-11-26 Constrain ANGLE_TUNE setting
    In case anyone wants to adjust it and doesn't have access to the register definition.
    [production.ino]
2019-11-26 scroll wheel is now done with a stochastic algorithm to make up for the inherent noise in the phototransistor
    [Scroller.cpp, production.ino]
2019-11-26 Cleanup, removing deprecated STEP files from old version.
    [Little Buttons.stp, MTBE-003.stp, MTBE-004.stp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]
2019-11-26 Small fixes for the roller dowel and primary buttons that address manufacturing issues. Changes improve probability that part will print properly.
    [Primary Buttons.stl, RollerBearingDowel.stl, RollerBearingDowel.stp]
2019-11-26 Design files, gerbers and schematics for R1.004 boards. Updated from R1.003.
    [Base.PcbDoc, Base.PrjPCB, Base.SchDoc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]
2019-12-18 altered wheels to have 13 holes instead of 20
    [ScrollWheel.stl, ScrollWheel.stp]
2020-01-22 added wedge
    [Wedge.stl, Wedge.stp]
2020-03-20 adjusted scroller array size to prevent int overflow errors when diodes give higher values
2020-04-27 Updated scroll wheel design to increase reliability.
    [ScrollWheel.stl]
2020-09-23 changes for r1.005 board revision
2020-10-15 updated schematic for r1.005 base board
2021-02-03 Add BTU modification (#18)
    * Add files for Ploopy top without bearing sockets
    - These files were created in Rhino by deleting the surfaces that made
    up the bearing sockets and patching the holes that were left
    - This is a good base for the BTU top or any other mods people want to
    make
    * Add BTU mod top piece v3
    - This is the first full version of the BTU mod I created.
    - v1 and v2 were just test pieces that mounted to the front screw
    holes of the trackball to check clearances. They weren't really a
    usable top as they didn't have anything other than the ball well.
    - This part has been test printed on an Ender 3 and works well.
    * Rename STEPs folder to STEP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
2021-02-15 Update BTU mod documentation (#19)
    * Clarify differences between BTU mod V3 and V4
    - Added description
    - V4 has now been tested so removed warning
    - Added better image of v3
    - Added image of v4
    * Update printing and assembly recommendations
    - The repo's wiki has much better 3D printing recommendations
    - Previously was missing any mention of the M3 threaded inserts which
    should be used. Now added and the wiki is also linked for those.
2021-02-22 added kit bearing press stls and steps to repo
    [Bit Bearing Press Complete.step, Kit Bearing Press Bottom.stl, Kit Bearing Press Top.stl]
2021-07-29 Add BTU mod for the REVC top (#22)
    * Remove V3 and V4 bearing tops based on REVA top
    - The ball used in newer Ploopy trackballs doesn't fit in the REVA top -
    it's just slightly too big.
    - I've designed an updated BTU mod for the REVC top, which should work
    fine with the older ball.
    * Move README images to img/ subfolder
    * Add blank REVC STEP and STL files
    - These are the official Ploopy Top REVC, edited to remove the bearing
    sockets.
    - The idea is that these can be used for any future mods to use
    different bearings.
    * Add REVC versions of the BTU top STEP and STL files
    * Rename v4 BTU mod FreeCAD file to match naming scheme
    * Remove FreeCAD file for v4 BTU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
2021-12-14 reorganized steps and stls
    [Bottom.STL, Primary Buttons.STL, Primary Buttons.stl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]
2022-02-10 Add new REV D version of BTU mod (#27)
    - This updates the BTU top to the REV D version of the Ploopy top, which
    is screwed together using self-tapping screws instead of M3 screws
    with threaded inserts.
    - This is untested so use at your own risk. There may be another change
    brought in with REV D that I've missed, and not copied into the mod's
    REV D.
2022-05-19 Widen ball well opening in REVD BTU mod (#30)
    * Widen ball well opening in REVD BTU mod
    - The ball opening had an overhang left from older versions, which
    should have been removed when updating for REVC or REVD. It's now been
    removed.
    - The actual ball well is still smaller than the official REVD
    top, but this makes it closer.
    * Rebase REVD changes onto REVC BTU top
    - In the previous commits I had mistakenly copied the Ploopy REVD
    changes onto a REVA BTU top. This meant that the ball well was too
    small if you had a REVC or REVD ball.
    - Now the ball well is the REVC version, with 47mm diameter. This should
    mean there's much more space for the larger ball!

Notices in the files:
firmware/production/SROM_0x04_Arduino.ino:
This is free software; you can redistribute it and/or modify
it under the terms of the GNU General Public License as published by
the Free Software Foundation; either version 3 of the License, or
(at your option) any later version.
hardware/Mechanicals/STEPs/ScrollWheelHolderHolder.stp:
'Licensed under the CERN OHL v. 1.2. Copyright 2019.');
